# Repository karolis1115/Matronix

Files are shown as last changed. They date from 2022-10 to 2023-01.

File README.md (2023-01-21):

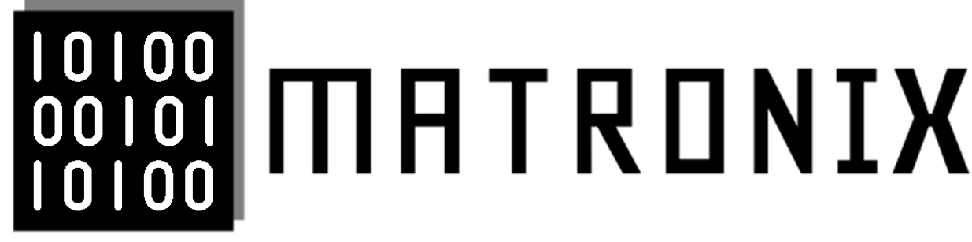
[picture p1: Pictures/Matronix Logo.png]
Matroniix

Saxion University of Applied Sciences Project Simulation & Integration 2022. 

# Team members
- Borna Modric 481209 481209@student.saxion.nl
- Joshua Phiri 511266 511266@student.saxion.nl
- Luuk Vulkers 523822 523822@student.saxion.nl
- Esther Ajumo 510127 510127@student.saxion.nl
- Karolis Juozapaitis 517546 517546@student.saxion.nl

# Goal
To make a modular, batery powered, wirelessly controlled RGB LED display board, while also designing a DC/DC converter based on given requirements.

# What is what
- CAD - CAD model designs for 3D printing
- PCB - Schematics, PCB, Gerber and other files
- Code - Place where all code is (test and main)
- Documents - Files such as Reports and project plans and so on
- Pictures - Project pictures and so on

# Libraries used
- LED Matrix Library + Recources https://github.com/hzeller/rpi-rgb-led-matrix
- ADS1x15 I2C ADC library https://learn.adafruit.com/adafruit-4-channel-adc-breakouts/python-circuitpython

# Sources
- https://www.raspberrypi.org/
- https://en.wikipedia.org/wiki/Raspberry_Pi
- https://github.com/hzeller/rpi-rgb-led-matrix

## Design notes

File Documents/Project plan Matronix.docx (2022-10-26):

# matronix Project plan

Project: MOdular led matrix scrolling display

Company: Matronix

Date:
Participants: | Project group LED matrix superstar McAwesomeville
| Borna Modric | 481209 | 481209@student.saxion.nl
| Joshua Phiri | 511266 | 511266@student.saxion.nl
| Luuk Vulkers | 523822 | 523822@student.saxion.nl
| Karolis Juozapaitis | 517546 | 517546@student.saxion.nl
| Esther Ajumo | 510127 | 510127@student.saxion.nl
Version | [1.1]
Clients | Saxion University of Applied Sciences
Tutor | Ali Yuksel

Table of Contents

# I. List of figures

# II. Abbreviations

DSP | Digital Signal Processing
FFT | Fast Fourier Transform
TL;DR | Too Long; Didn’t Read
LED | Light Emitting Diode

# introduction

## backround

Team Matronix is a company founded in 2022 as a part of a university project for the class Project Simulation & Realization. It consists of a group of five students from Saxion University of Applied Sciences majoring in Electrical Engineering.

This company has as a main goal to design a fully functional RGB LED sign and document every step of the development of the project.

The team is ready and confident to offer the best quality possible in their products and to comply to their clients’ demands.

## Description

Our team was tasked with creating a wireless programmable LED message sign board for users to display a message they wish. The team came up with a simple solution to the client’s needs, a sign with multiple modular displays that can be configured based on the user’s needs to create a better viewing experience for viewers.

## MoSCoW Method

One of the methods that will be used is The MoSCoW which operates by splitting the clients’ requirements into the most important ("Must"), all the way down to additions which would be nice to have, but are not necessary ("Could"), while also agreeing on things which are not feasible due to either timing issues or just not enough manpower ("Won’t have").

Must:

- Clearly visible from 10m
- Mobile
- Cordless
- Energy via battery
- Wireless data transmission
- Battery life for at least 1 hour
- Display must scroll the text.

Should:

- Battery life of 3 hours
- Wide enough for clear messages

Could:

- Display weather information when not used
- Speaker to read messages that are displayed
- Magnet connection
- Scalable and modular design
- Modular batteries
- Hot swappable batteries
- Display GIFs and videos
- Display images or videos
- Modules for additional features (temperature, humidity, and so on).

Won’t have:

- Infinitely scalable display
- Power form solar panels
- Replaceable LEDs (in case one breaks)
- Connect external Display (LCD, OLED, …) for extension
- Use device as monitor with display input (HDMI, VGA, Composite)

# Project Objectives

The project objectives include:

- The project is designed for maximum energy efficiency
- The text must be readable from a 10 meters distance.
- The text display should be multi color (RGB).
- The power supply via a battery.
- The communication to the system must be wireless
- The project group has regular updates with the client.

Aside from these strict requirements, we also implemented some secondary objectives we mean to implement in our project.

- The project will use multiple display modules side to side/stacked up.
- Make displays modular/work independently by disconnecting and reconnecting them
- Use high-current batteries to provide enough current
- Implement hot-swappable batteries
- 3D-printed and/or laser cut casing
- Use magnets and pogo-connectors to connect and disconnect the displays.
- If displays are disconnected, display different messages.

# Project activities

The project activities are divided into three stages

Preparatory stage:

- creation of a final concept
- Assigning organizational roles
- Making a project plan (also, in documentation)
- Cost estimation and budgeting
- Assigning deliverables

Design and implementation stage

- Making a functional and technical design (also, in documentation)
- Creating the product (hardware and software implementation)
- Testing the product
- Product assembly
- Progress report presentation (weekly)

Final stage

- Final Product delivery
- Documentation of the process in the form of a final report and presentation.

# Project boundaries (scope and pre-conditions)

The project has a duration of two quarters, which is about 4 months estimated. In terms of project width, there was no clear instruction on what is outside the scope of the project, only basic conditions. Based on the client’s requirements, the product should be mobile, cordless, powered by a battery, show a text in multicolor and readable from ten meters away. To make the project a success, those conditions must be fulfilled.

A budget of 75Euros has been given to acquire materials needed for this project, the final product is to be delivered by the sixth week of the second quarter

# Quality assurance

Matronix is committed to delivering a product of immense quality for our clients. Each employee has been involved in a prior project of some sort that requires them to apply their Electrical and Electronic skills and knowledge, in addition, the company has weekly meetings with the sponsor to ensure the product is developing in accordance with the requirements, moreover, the sponsor has access to various intermediate results (Project Plan, Functional Design, Technical Design & Final Report) and can, in turn, provide feedback when needed, thus validating the company’s claims of providing a high-end product at the end of this project.

Delivering a high-quality product crucial to a product's success. Therefore, the sponsor participates in the assessment of the project by testing the final product, they will thoroughly assess the product and decide whether it satisfies all the previously stated requirements or not

The sponsor will verify the following specifications to ensure that Matronix has in fact implemented these specifications in the product.

System specs

1. Designed for maximum energy efficiency ideally last for 30min on one charge

2. Text must be readable from a 10-meter distance and must be mobile

3. The text display should be multi-colour.

4. The power supply via a battery.

5. The communication to the system must be wirelessly.

Matronix will ensure this project is conducted with the utmost regard for the safety of each participant during the project, as well as creating a safe product for the client. There are no major safety threats involved with this project therefore, adhering to standard laboratory safety rules will be sufficient.

# Project organization

See Project Management from Roel Grit.

## Organisation

The Project organization is as follows:

- Joshua Electronics/Programming Group lead 511266@student.saxion.nl
- Karolis Electronics/Programming 517546@student.saxion.nl
- Borna Power delivery 481209@student.saxion.nl
- Esther Power delivery Minute taker 510127@student.saxion.nl
- Luuk Power/2D -3D modelling 523822@student.saxion.nl

## Information

Stakeholders

- The project group members
  - Borna Modric
  - Joshua Phiri
  - Luuk Vulkers
  - Karolis Juozapaitis
  - Esther Ajumo
- Tutor
  - Ali Yuksel
- The client
  - Saxion University of Applied Sciences

Communication

Within the project group we will weekly have two meetings. Aside from these, there is a Discord server for online communication and group calls. Minutes are updated weekly to check back on what has been happening, and it can be found on Blackboard.

Communication with the client will be had with regular client meetings. These will occur in the following weeks:

  - Week 1.3
    - Project Plan presentation
  - Week 1.6
    - Final Technical Design
  - Week 1.8
    - Midterm Presentation
  - Week 2.1
  - Week 2.4
  - Week 2.6
    - Demonstration final product

# Planning

- See GAANT Chart

# Costs and benefits

- As the project will be done using MOSCOW the final costs of the projects can only be predicted and are likely subject to change during the development process due to design changes and/or fixes. Simply speaking more features will likely include a higher cost. (Time and money)

Part & Link (Preliminary) | Quantity (Preliminary) | Price/pcs. (excl. VAT) (Preliminary)
64x32 RGB LED Matrix - 320x160mm (https://www.tinytronics.nl/shop/en/lighting/matrix/64x32-rgb-led-matrix-320x160-mm) | 2 Pcs. | € 21.07
1. ESP32-WROVER WiFi Module - PCB Antenna (https://www.tinytronics.nl/shop/en/communication-and-signals/wireless/wi-fi/modules/esp32-wrover-wifi-module-pcb-antenna-connector) | 1 pcs. | € 4.55
Battery
Misc.
DC/DC Converter
Logic Level Shifter

- While monetary costs are important to figure out if the project is in scope of the given budget. Time is a constraint that should also be taken into account. Even when everything is in order what could result in a failed project is incorrectly set deadlines for each part of the project. This should be taken into account in the GAANT chart.
- The end result will be a fully functional, battery powered and wirelessly controlled scrolling display board that would allow to quickly and easily communicate any important notices, information or updates without physically interacting with the device itself. Assuming enough time is present additional features will be added the features mentioned are included in the MOSCOW section
- As for the compensation of the team members. A sufficient grade is the bare minimum that Is agreed upon. Fulfilling all the stated requirements should result in a perfect grade.

# Bibliography

Grit, R. (2010). Project managment. Noordhoff Uitgevers.

# Appendix A Gantt chart

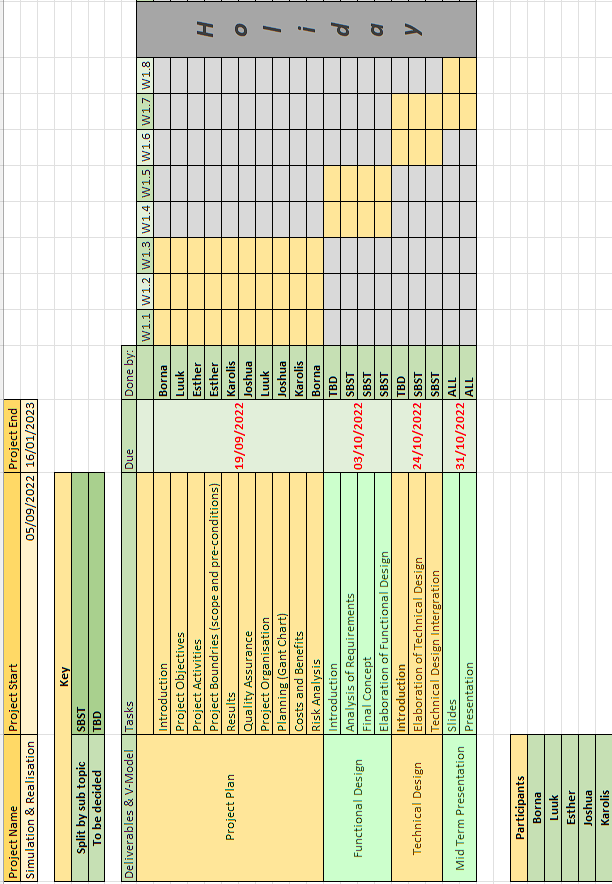
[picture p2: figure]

# Appendix B Risk analysis

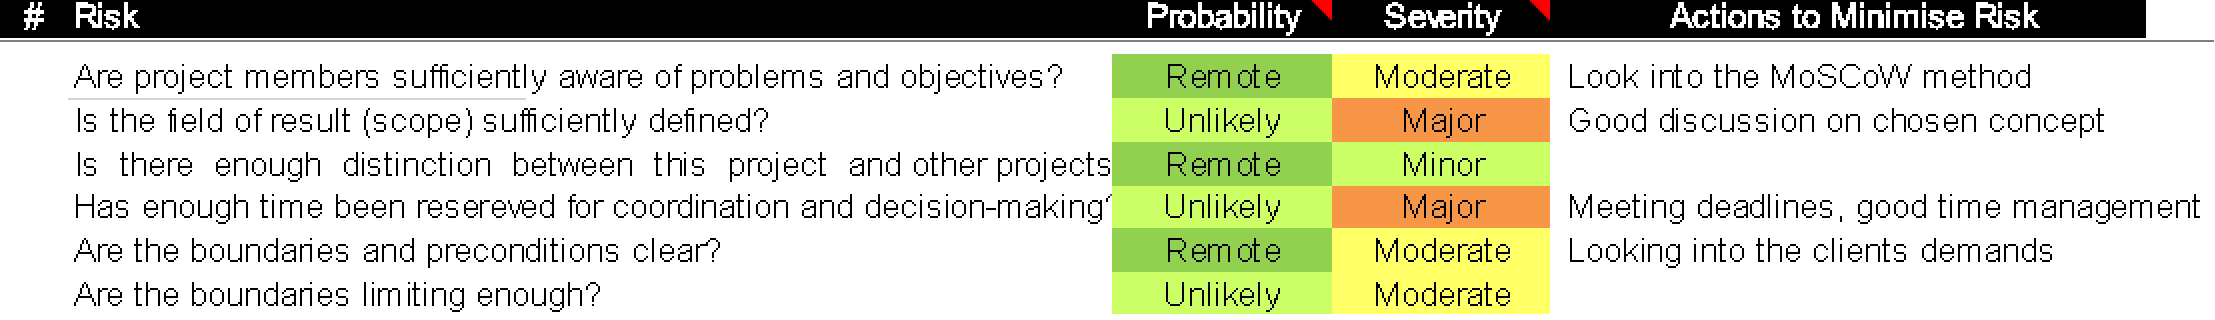
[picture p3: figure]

Project Plan version no: 2

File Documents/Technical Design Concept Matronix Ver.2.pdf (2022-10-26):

# 10/24/2022 Concept Technical

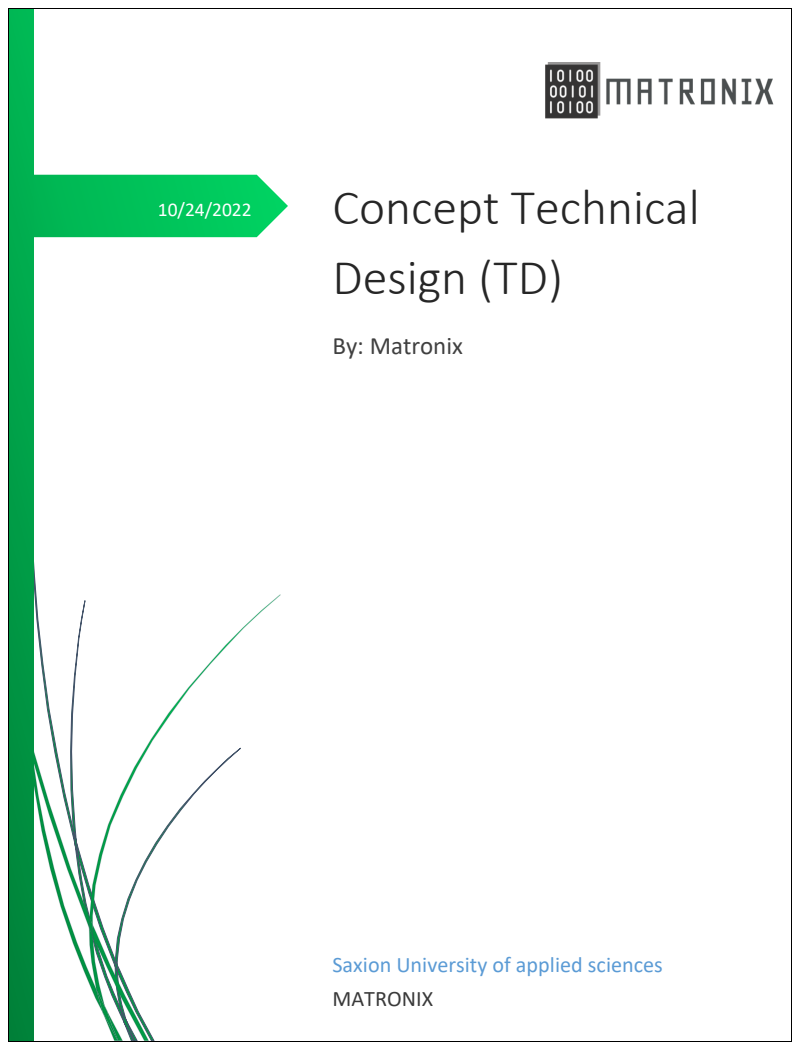
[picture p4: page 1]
Design (TD); By: Matronix

Saxion University of applied sciences
MATRONIX

Place, date: | Enschede, 13.10.2022.
Prepared by: | Team Matronix
| Luuk Vulkers | 523822 | 523822@student.saxion.nl
| Borna Modric | 481209 | 481209@student.saxion.nl
| Karolis Juozapaitis | 517546 | 517546@student.saxion.nl
| Esther Ajumo | 510127 | 510127@student.saxion.nl
| Joshua Phiri | 511266 | 511266@student.saxion.nl
Version number: | 1
Clients: | Ali Yuksel

iii

CONTENTS

iv

ABBREVIATIONS

- LED – Light Emitting Diode
- SDK – Source Development kit
- API – Application Programming Interface
- Li-Ion – Lithium Ion (Battery)
- BMS – Battery Management System

INTRODUCTION

Matronix’ technical design document is an overview of the technical details that will be considered during the implementation phase. These details include concept selection, component choice, and software and hardware flowcharts. This document will also help understand the main reasons for this project.

PROBLEM

The task provided to Team Matronix is to develop an RGB LED display sign for users to show their messages on it. The display must be readable from 10 meters, have at least 1 hour of battery life, the sign must be mobile and cordless.

`

ELABORATION OF CHOSEN PRINCIPLE TO TECHNICAL DESIGN

Matronix decided to go with a concept of detachable modular displays and hot swappable batteries The displayed text/graphics will adjust based on the number of displays connected, and brightness will be adjusted based on the amount of battery modules/pack connected.

OVERVIEW OF TECHNICAL DESIGN

In this concept, the LED displays will be detachable modules each with its own hot swappable battery. The display size can be increased or decreased by adding or removing LED Matrix modules and the batteries can be removed, replaced or charged without interrupting the operation of the display. This concept allows for the creation of a very efficient display having minimal power and size problems.

ELABORATION OF TECHNICAL DESIGN

ELECTRICAL & ELECTRONICS CIRCUITS

Show in Appendix A is a schematic of the PCB which will be physically attached to the main display, its purpose is to house the raspberry pi 4b Microcomputer as well as serve as a connection point for the other matrix panel modules to the Microcomputer.

Subcircuits of this schematic are panel detection circuits as well as battery pack detection circuitry.

The other schematics in Appendix A include the power delivery, charging and balancing circuitry.

SOFTWARE

- https://github.com/hzeller/rpi-rgb-led-matrix Library, Resources, Example code

- https://github.com/karolis1115/Matronix Project Repository (GitHub)

TECHNICAL DESIGN INTEGRATION

SAFETY

- Since the Li-Ion battery cells that are used to power the project are potentially dangerous and can lead to unforeseen consequences, care has been taken to implement multiple safety features:
- Over-charge protection
- Over-discharge protection
- Power delivery to the battery is controlled by a USB-C PD (Power delivery) integrated circuit
- Charging is controlled by a dedicated integrated circuit that charges and balances the 2 cells in series that will be used for the battery pack
- The Raspberry pi will have the capability to detect how many battery packs are connected to each display, if the amount of battery packs connected is less than the battery backs can handle the brightness will be dimmed to reduce power consumption and extend battery life. (Each pack can run 2 displays)

COSTS

Due to the sheer amount of engineering that goes into making a modular design of any product high costs are to be expected.

The main costs can be divided into these categories:

- Battery power and battery power management
- Charging
- Voltage conversion
- Battery cell protection (Undervoltage, Overcharging, Automatic sufficient charging supply assertion, …)
- Display and display management
- Display data level shifting
- Display detection using an ADC

- Display modularity integration

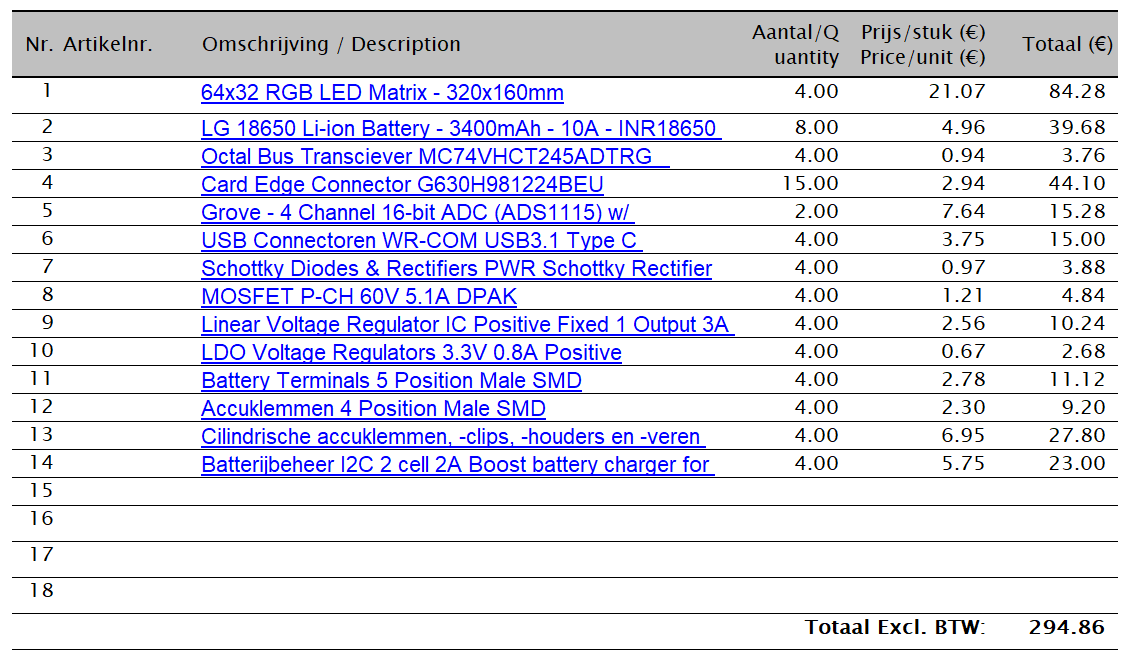
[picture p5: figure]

MAINTENANCE

A big part of the concept of this system is that the components are modular, this brings an advantage when a part becomes faulty or reaches its end of life it can be easily swapped out for a new one without soldering.

- The battery packs contain holders for the 18650 cells that will be used to power the device so it’s easy to repair the battery module itself.
- The raspberry pi, and display matrix modules will be connected to a PCB using headers so replacing either the Matrix panel or the raspberry pi itself should only require a screwdriver.

APPENDIX A: ELECTRICAL & ELECTRONIC

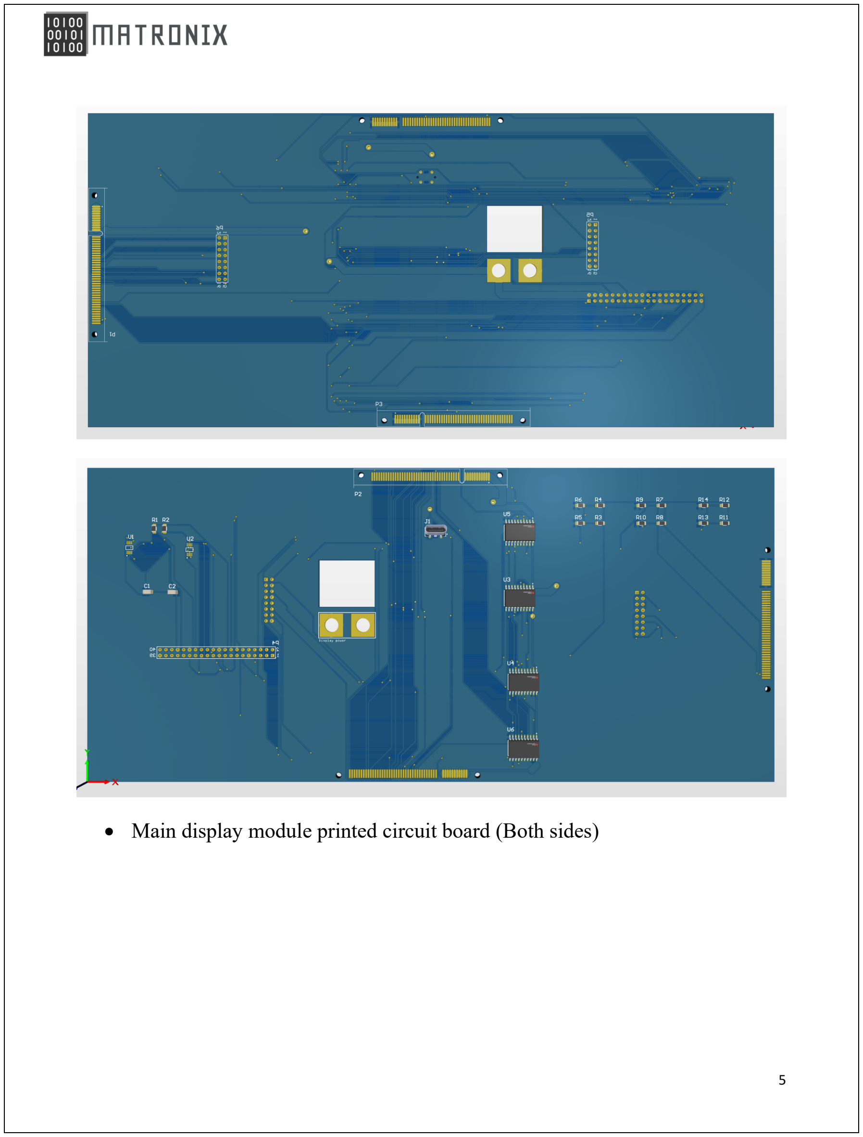
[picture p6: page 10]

- Main display module printed circuit board (Both sides)

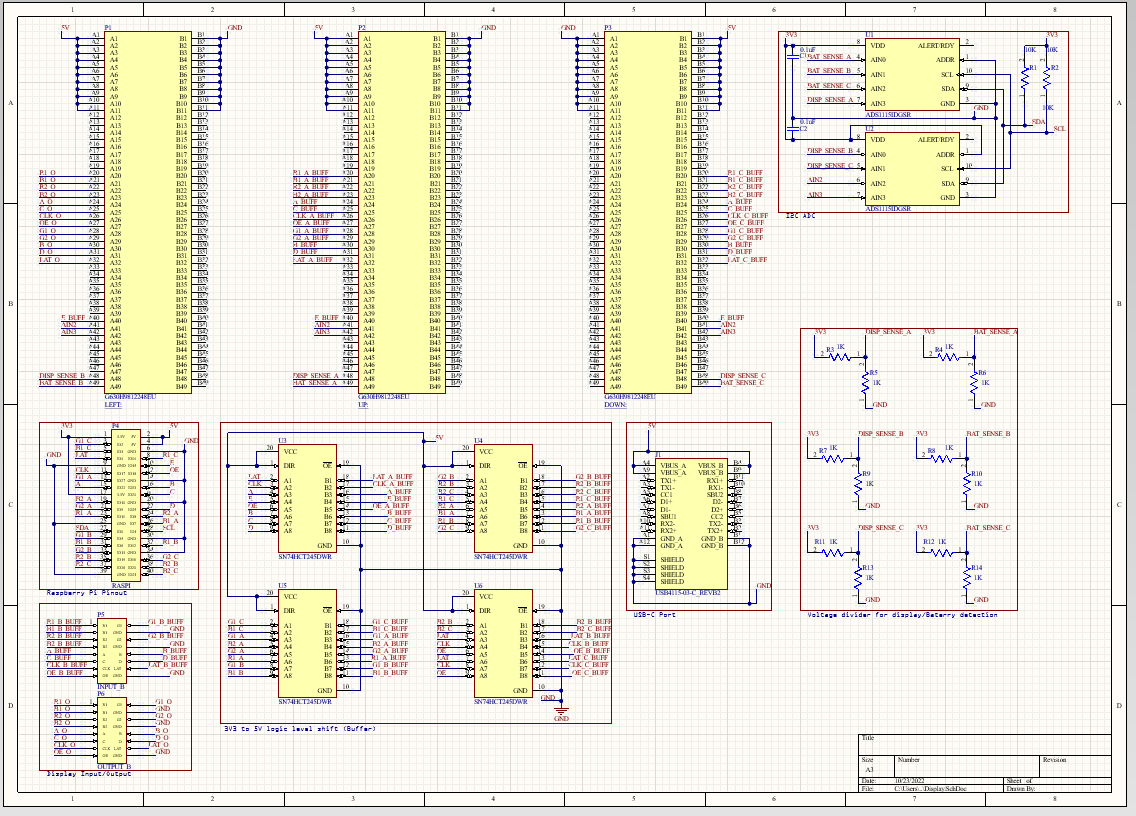
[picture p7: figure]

- Main display Circuit schematic (data output, Logic level conversion, baterry, display detection, ADC integration)

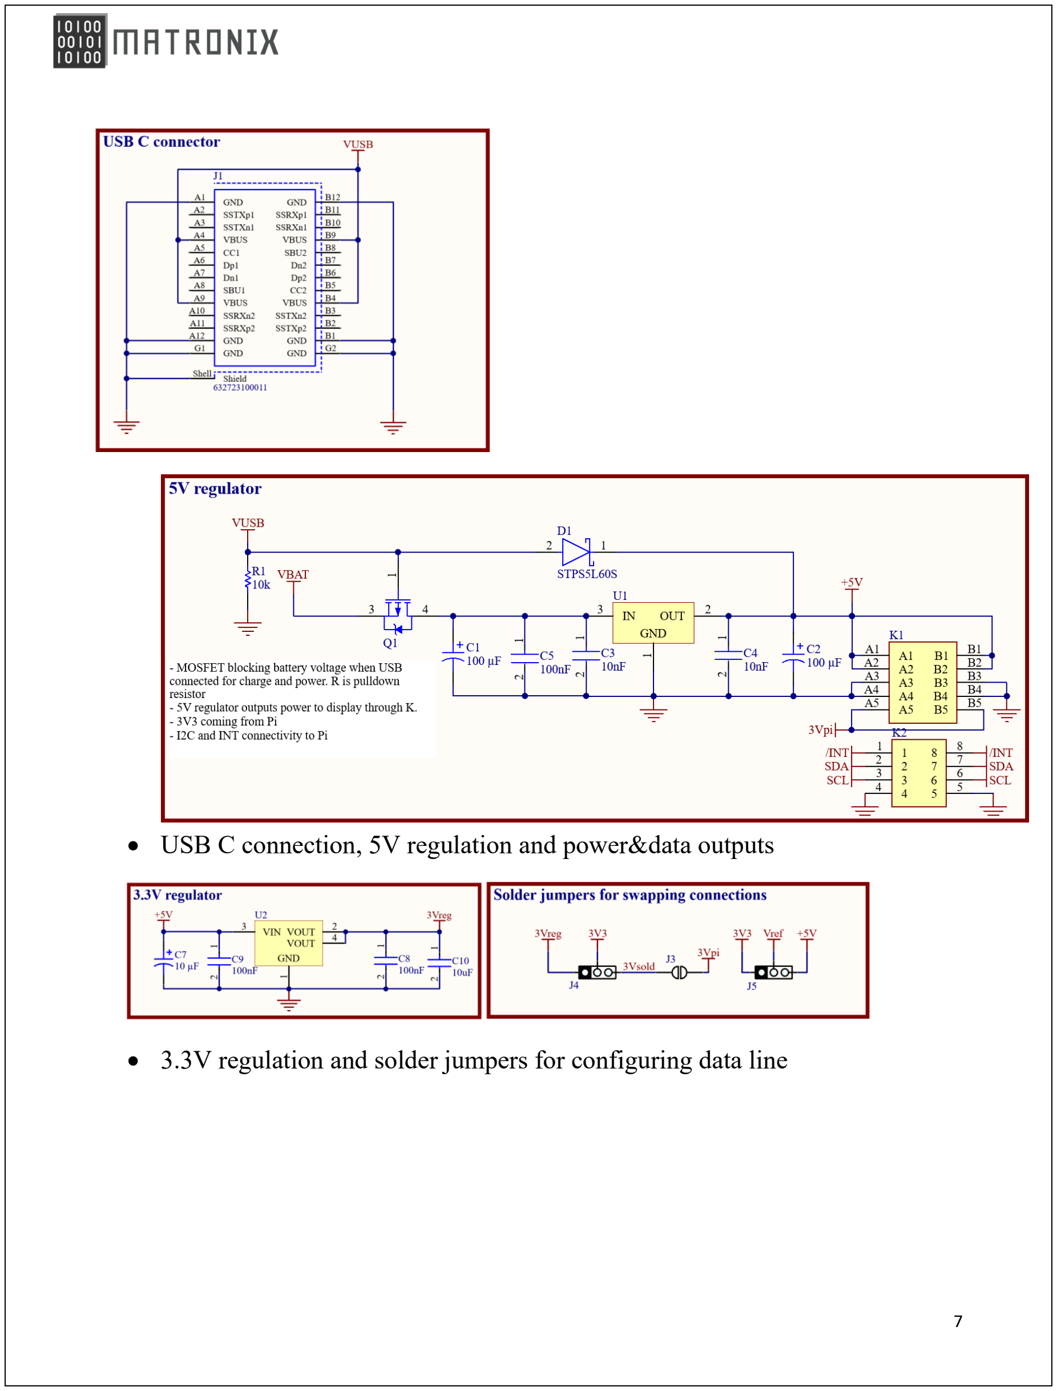
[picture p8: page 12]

- USB C connection, 5V regulation and power&data outputs
- 3.3V regulation and solder jumpers for configuring data line

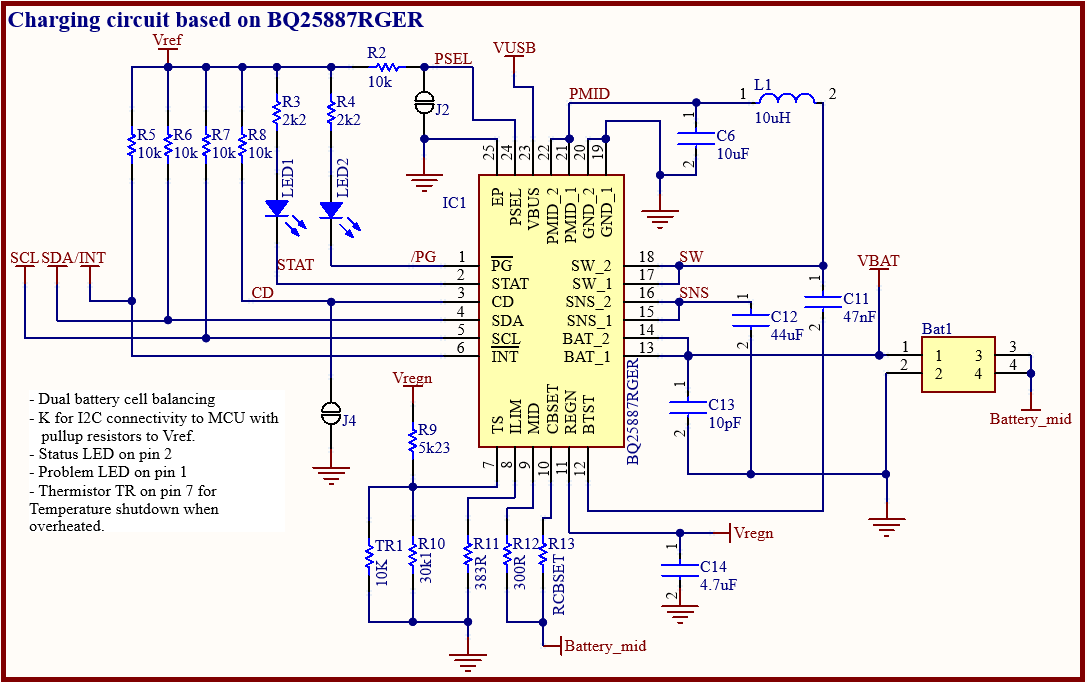
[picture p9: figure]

- Battery Charging/Protection

DISPLAY DEMONSTRATION

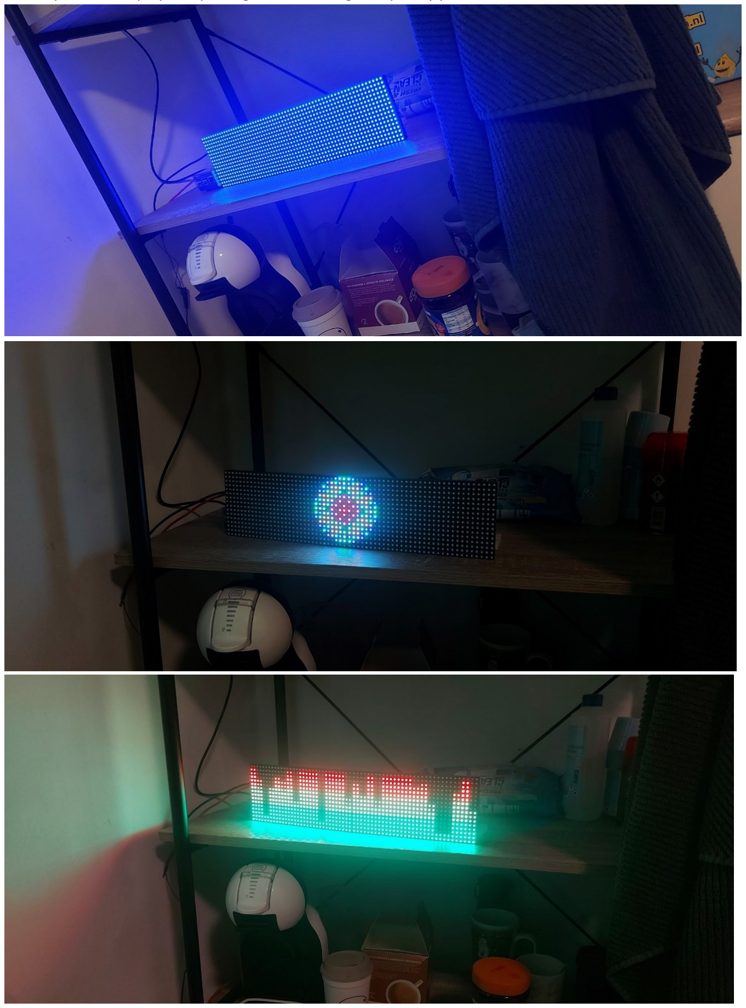
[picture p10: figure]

This depicts the displays outputting Patterns using a raspberry pi 4B

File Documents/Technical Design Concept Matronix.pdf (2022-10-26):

# 10/24/2022 Concept Technical

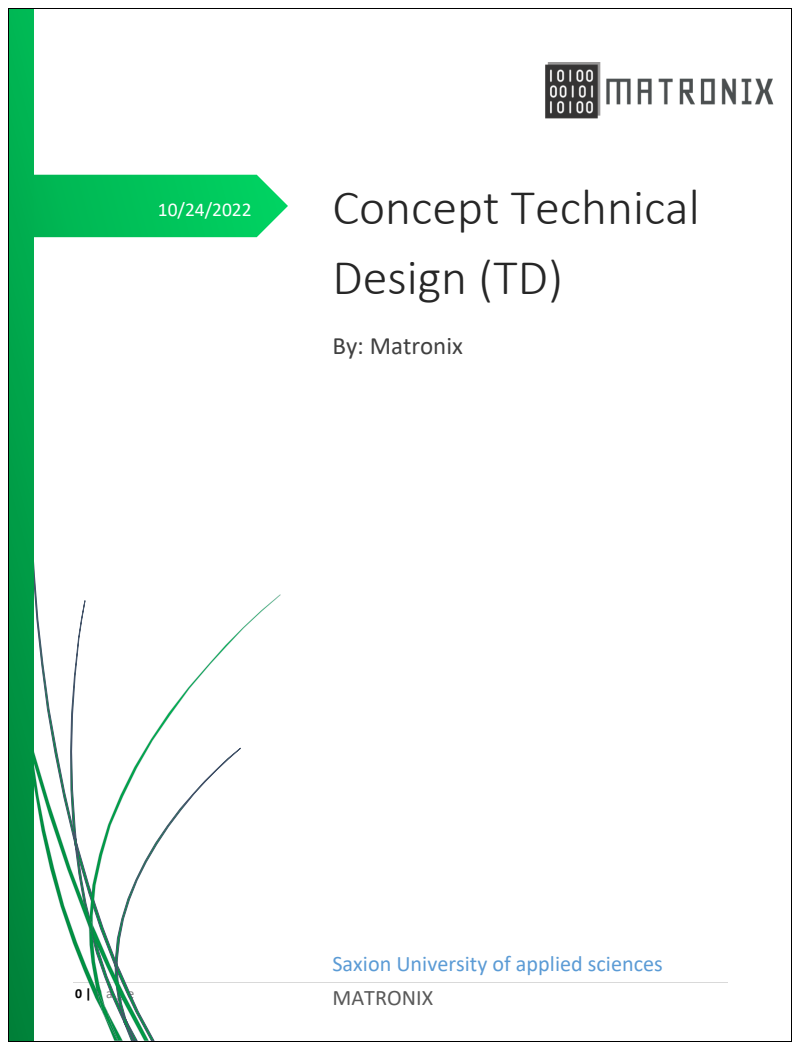
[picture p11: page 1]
Design (TD); By: Matronix

Saxion University of applied sciences
MATRONIX

Place, date: | Enschede, 13.10.2022.
Prepared by: | Team Matronix
| Luuk Vulkers | 523822 | 523822@student.saxion.nl
| Borna Modric | 481209 | 481209@student.saxion.nl
| Karolis Juozapaitis | 517546 | 517546@student.saxion.nl
| Esther Ajumo | 510127 | 510127@student.saxion.nl
| Joshua Phiri | 511266 | 511266@student.saxion.nl
Version number: | 1
Clients: | Ali Yuksel

iii

CONTENTS

iv

ABBREVIATIONS

- LED – Light Emitting Diode
- SDK – Source Development kit
- API – Application Programming Interface
- Li-Ion – Lithium Ion (Battery)
- BMS – Battery Management System

INTRODUCTION

Matronix’ technical design document is an overview of the technical details that will be considered during the implementation phase. These details include concept selection, component choice, and software and hardware flowcharts. This document will also help understand the main reasons for this project.

PROBLEM

The task provided to Team Matronix is to develop an RGB LED display sign for users to show their messages on it. The display must be readable from 10 meters, have at least 1 hour of battery life, the sign must be mobile and cordless.

`

ELABORATION OF CHOSEN PRINCIPLE TO TECHNICAL DESIGN

Matronix decided to go with a concept of detachable modular displays and hot swappable batteries The displayed text/graphics will adjust based on the number of displays connected, and brightness will be adjusted based on the amount of battery modules/pack connected.

OVERVIEW OF TECHNICAL DESIGN

In this concept, the LED displays will be detachable modules each with its own hot swappable battery. The display size can be increased or decreased by adding or removing LED Matrix modules and the batteries can be removed, replaced or charged without interrupting the operation of the display. This concept allows for the creation of a very efficient display having minimal power and size problems.

ELABORATION OF TECHNICAL DESIGN

ELECTRICAL & ELECTRONICS CIRCUITS

Show in Appendix A is a schematic of the PCB which will be physically attached to the main display, its purpose is to house the raspberry pi 4b Microcomputer as well as serve as a connection point for the other matrix panel modules to the Microcomputer.

Subcircuits of this schematic are panel detection circuits as well as battery pack detection circuitry.

The other schematics in Appendix A include the power delivery, charging and balancing circuitry.

SOFTWARE

- https://github.com/hzeller/rpi-rgb-led-matrix Library, Resources, Example code

- https://github.com/karolis1115/Matronix Project Repository (GitHub)

TECHNICAL DESIGN INTEGRATION

SAFETY

- Since the li-Ion battery cells that are used to power the project are potentially dangerous and can lead to unforeseen consequences, care has been taken to implement multiple safety features:
- Over-charge protection
- Over-discharge protection
- Power delivery to the battery is controlled by a USB-C PD (Power delivery) integrated circuit
- Charging is controlled by a dedicated integrated circuit that charges and balances the 2 cells in series that will be used for the battery pack
- The Raspberry pi will have the capability to detect how many battery packs are connected to each display, if the amount of battery packs connected is less than the battery backs can handle the brightness will be dimmed to reduce power consumption and extend battery life. (Each pack can run 2 displays)

COSTS

expensive

MAINTENANCE

A big part of the concept of this system is that the components are modular, this brings an advantage when a part becomes faulty or reaches it’s end of life it can be easily swapped out for a new one without soldering.

- The battery packs contain holders for the 18650 cells that will be used to power the device so it’s easy to repair the battery module itself.
- The raspberry pi, and display matrix modules will be connected to a PCB using headers so replacing either the Matrix panel or the raspberry pi itself should only require a screwdriver.

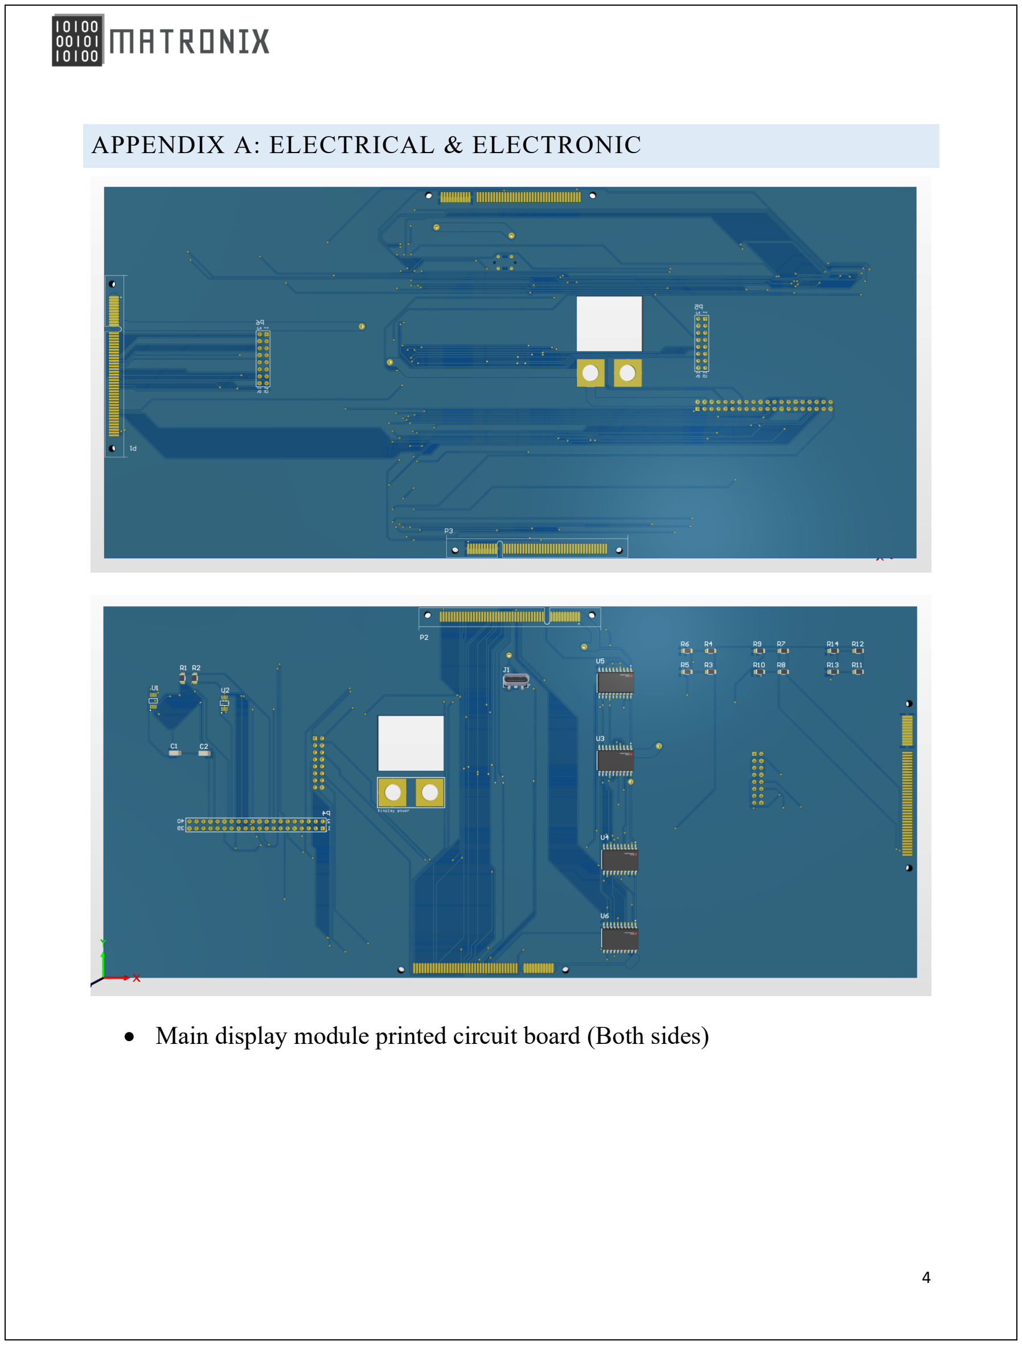
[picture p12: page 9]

APPENDIX A: ELECTRICAL & ELECTRONIC

- Main display module printed circuit board (Both sides)


- Main display Circuit schematic (data output, Logic level conversion, baterry, display detection, ADC integration)

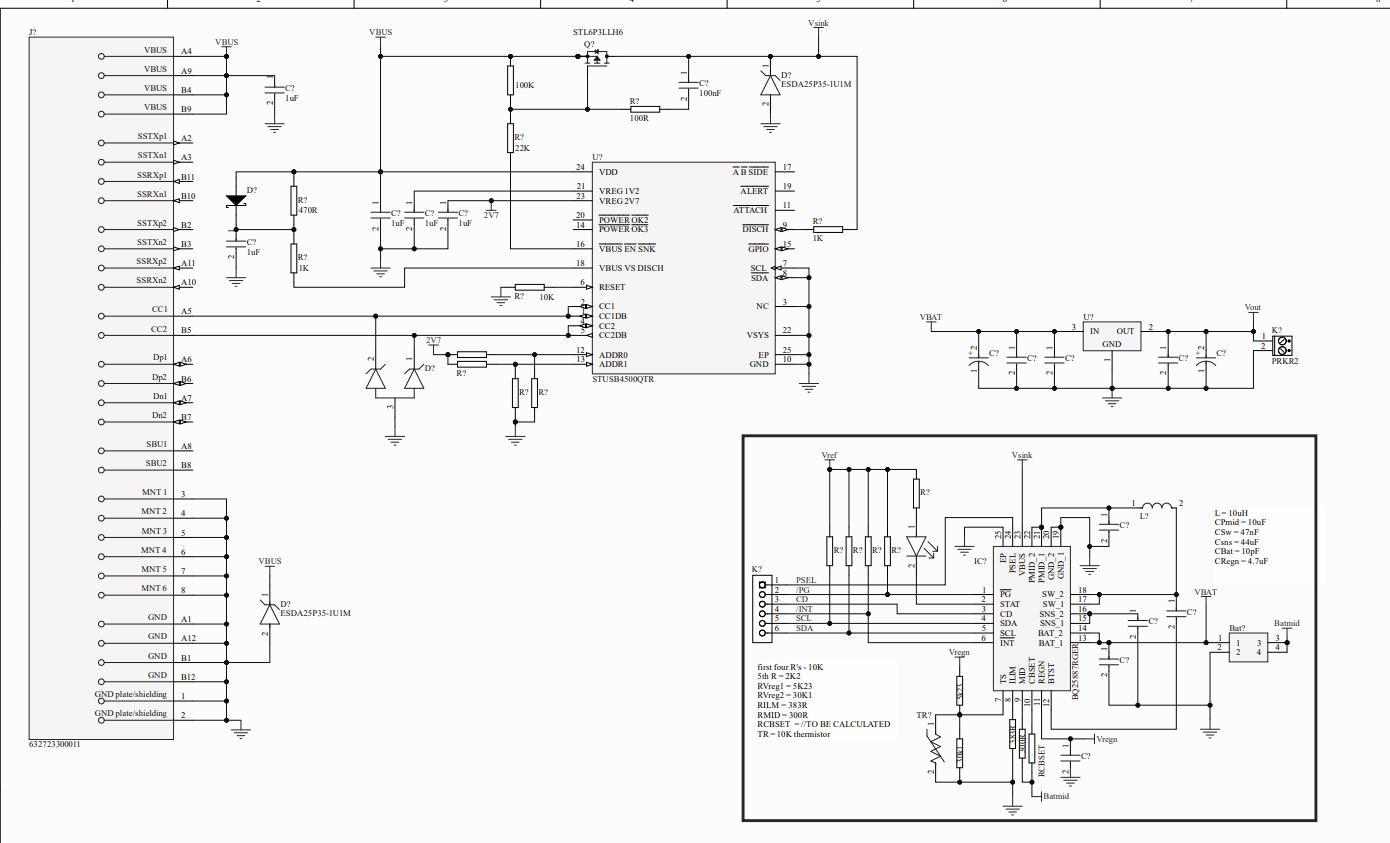
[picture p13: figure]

- Battery Charging/Protection and power output circuitry

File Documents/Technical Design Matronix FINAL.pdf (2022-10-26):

# 10/24/2022 Technical Design

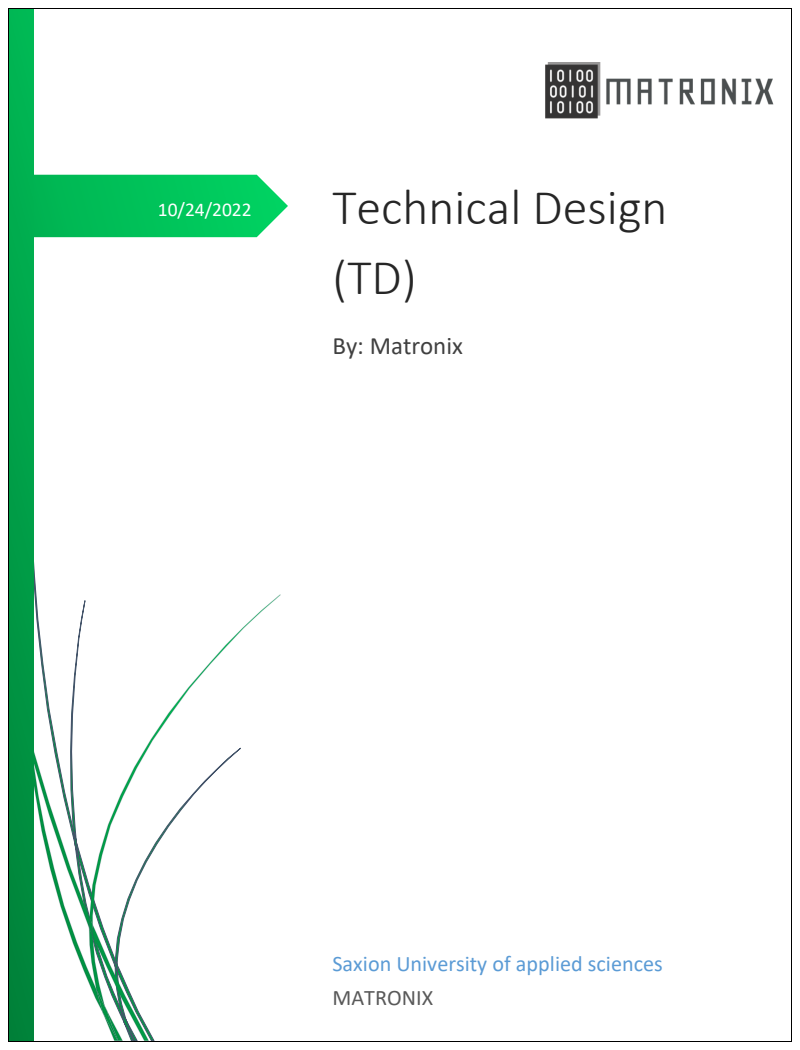
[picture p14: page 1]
By: Matronix

Saxion University of applied sciences
MATRONIX

Place, date: | Enschede, 13.10.2022.
Prepared by: | Team Matronix
| Luuk Vulkers | 523822 | 523822@student.saxion.nl
| Borna Modric | 481209 | 481209@student.saxion.nl
| Karolis Juozapaitis | 517546 | 517546@student.saxion.nl
| Esther Ajumo | 510127 | 510127@student.saxion.nl
| Joshua Phiri | 511266 | 511266@student.saxion.nl
Version number: | 1
Clients: | Ali Yuksel

iii

CONTENTS

iv

ABBREVIATIONS

- LED – Light Emitting Diode
- SDK – Source Development kit
- API – Application Programming Interface
- Li-Ion – Lithium Ion (Battery)
- BMS – Battery Management System

INTRODUCTION

Matronix’ technical design document is an overview of the technical details that will be considered during the implementation phase. These details include concept selection, component choice, and software and hardware flowcharts. This document will also help understand the main reasons for this project.

PROBLEM

The task provided to Team Matronix is to develop an RGB LED display sign for users to show their messages on it. The display must be readable from ten meters, have at least 1 hour of battery life, the sign must be mobile and cordless.

`

ELABORATION OF CHOSEN PRINCIPLE TO TECHNICAL DESIGN

The concept chosen by Matronix abides to all the requirements requested by the stakeholders:

- Wireless data transmission – Using Raspberry pi’s Wi-Fi and SSH or Webserver.
- Clearly readable from ten meters far – The chosen display size provides adequate clarity and readability. In case the desired distance is largely more than ten meters additional modules can be easily attached.
- The display will run for at least an hour as power will be provided by battery modules consisting of two rechargeable 18650 Li-Ion battery cells connected in series with charging, power regulation and safety features. One battery module will be chosen per display to achieve maximum performance and battery life.

The summary or additional features that this product will have are as follow:

- Detachable modular displays
- Hot swappable batteries – Display operation will not be interrupted if at least one battery module is connected
- Automatic Displayed text/graphics Size adjustment based on the amount of displays connected
- Automatic brightness adjustment based on the amount of battery modules connected
- Mounting the displays back-to back will allow displaying the same information from the front and back for people to see from both sides of the display.
- The ports that connect the display modules will also allow for additional modules or sensors to be connected by the I2C BUS and 2 ADC inputs, to add to that any unused IO that would normally be used for additional display modules can be used for additional peripherals instead.

OVERVIEW OF TECHNICAL DESIGN

In this concept, the LED displays will be detachable modules each with its own hot swappable battery. The display size can be increased or decreased by adding or removing LED Matrix modules and the batteries can be removed, replaced, or charged without interrupting the operation of the display. This concept allows for the creation of a very efficient display having minimal power and size problems.

ELABORATION OF TECHNICAL DESIGN

ELECTRICAL & ELECTRONICS CIRCUITS

Show in Appendix A is a schematic of the PCB which will be physically attached to the main display, its purpose is to house the raspberry pi 4b Microcomputer as well as serve as a connection point for the other matrix panel modules to the Microcomputer.

Subcircuits of this schematic are panel detection circuits as well as battery pack detection circuitry.

The other schematics in Appendix A include the power delivery, charging and balancing circuitry.

SOFTWARE

- https://github.com/hzeller/rpi-rgb-led-matrix Library, Resources, Example code
- https://github.com/karolis1115/Matronix Project Repository (GitHub)

TECHNICAL DESIGN INTEGRATION

SAFETY

- Since the Li-Ion battery cells that are used to power the project are potentially dangerous and can lead to unforeseen consequences, care has been taken to implement multiple safety features:
- Over-charge protection

- Over-discharge protection
- Power delivery to the battery is controlled by a USB-C PD (Power delivery) integrated circuit
- Charging is controlled by a dedicated integrated circuit that charges and balances the two cells in series that will be used for the battery pack
- The Raspberry pi will have the capability to detect how many battery packs are connected to each display, if the amount of battery packs connected is less than the battery backs can handle the brightness will be dimmed to reduce power consumption and extend battery life. (Each pack can run two displays)

COSTS

Due to the sheer amount of engineering that goes into making a modular design of any product excessive costs are to be expected.

The main costs can be divided into these categories:

- Battery power and battery power management
- Battery cell costs
- Charging
- Voltage conversion
- Battery cell protection (Undervoltage, Overcharging, Automatic sufficient charging supply assertion, …)
- Display and display management
- Display module costs
- Display data voltage level shifting
- Display detection using an ADC
- Display modularity integration

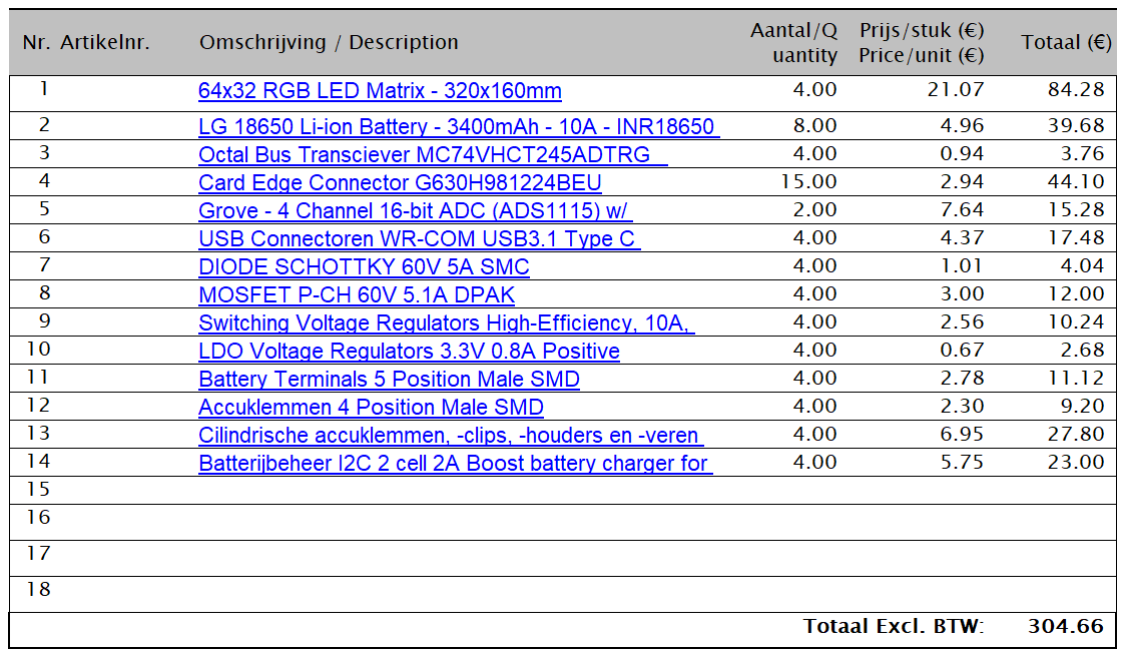
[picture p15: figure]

MAINTENANCE

A big part of the concept of this system is that the components are modular, this brings an advantage when a part becomes faulty or reaches its end of life it can be easily swapped out for a new one without soldering.

- The battery packs contain holders for the 18650 cells that will be used to power the device, so it is easy to repair the battery module itself.
- The raspberry pi, and display matrix modules will be connected to a PCB using headers so replacing either the Matrix panel or the raspberry pi itself should only require a screwdriver.

APPENDIX A: ELECTRICAL & ELECTRONIC

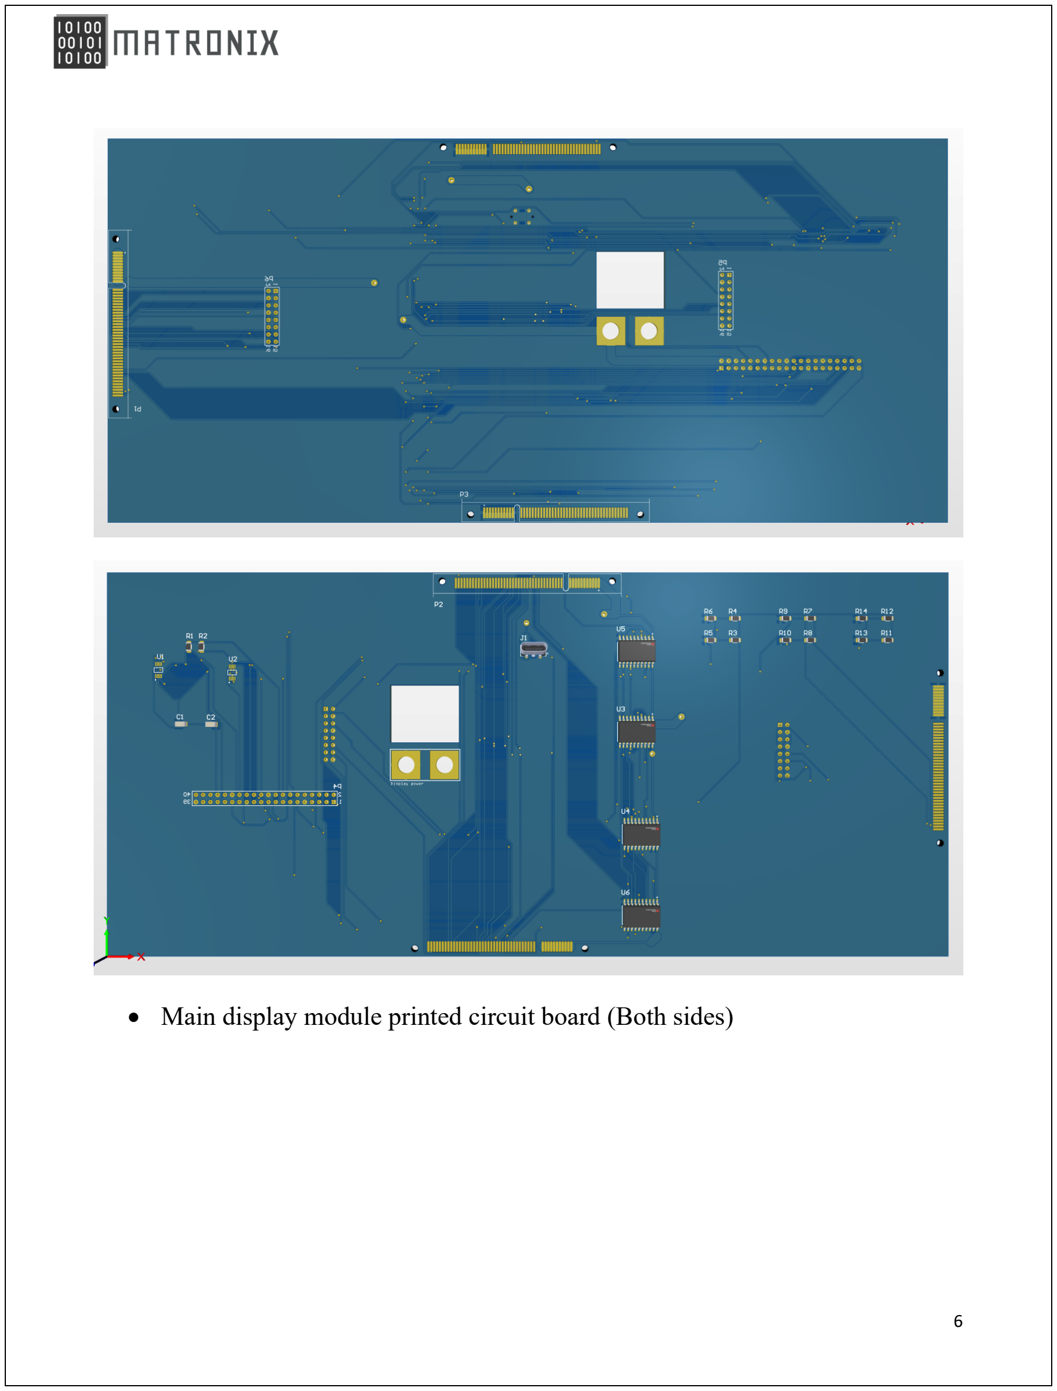
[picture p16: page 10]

- Main display module printed circuit board (Both sides)


- Main display Circuit schematic (data output, Logic level conversion, battery, display detection, ADC integration)

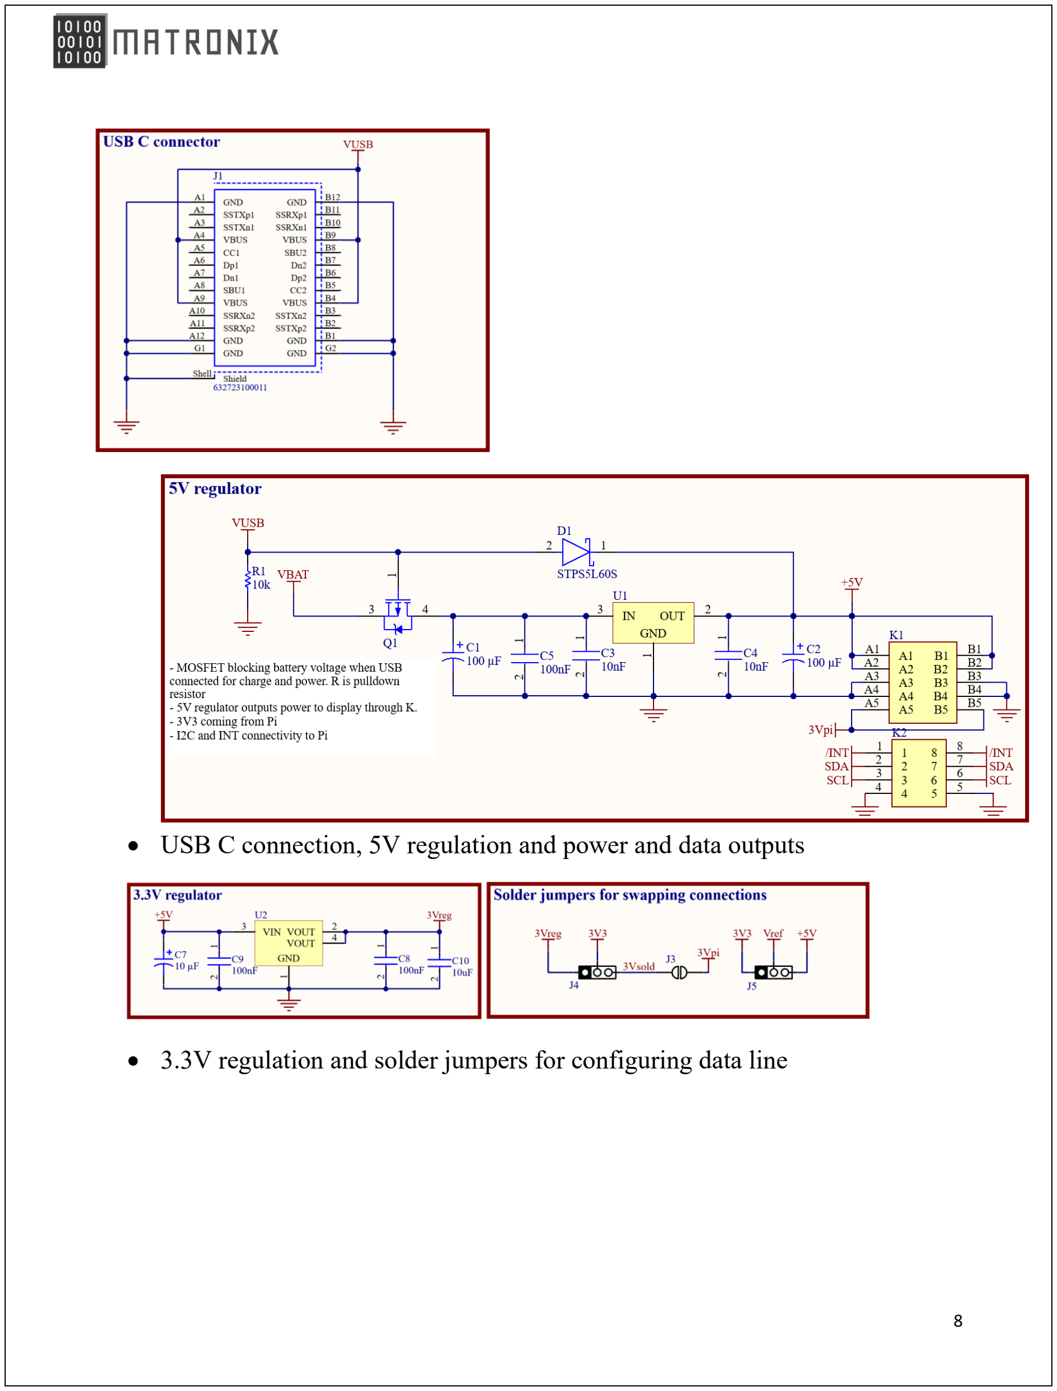
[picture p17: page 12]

- USB C connection, 5V regulation and power and data outputs
- 3.3V regulation and solder jumpers for configuring data line


- Battery Charging/Protection

DISPLAY DEMONSTRATION
This depicts the displays outputting Patterns using a raspberry pi 4B

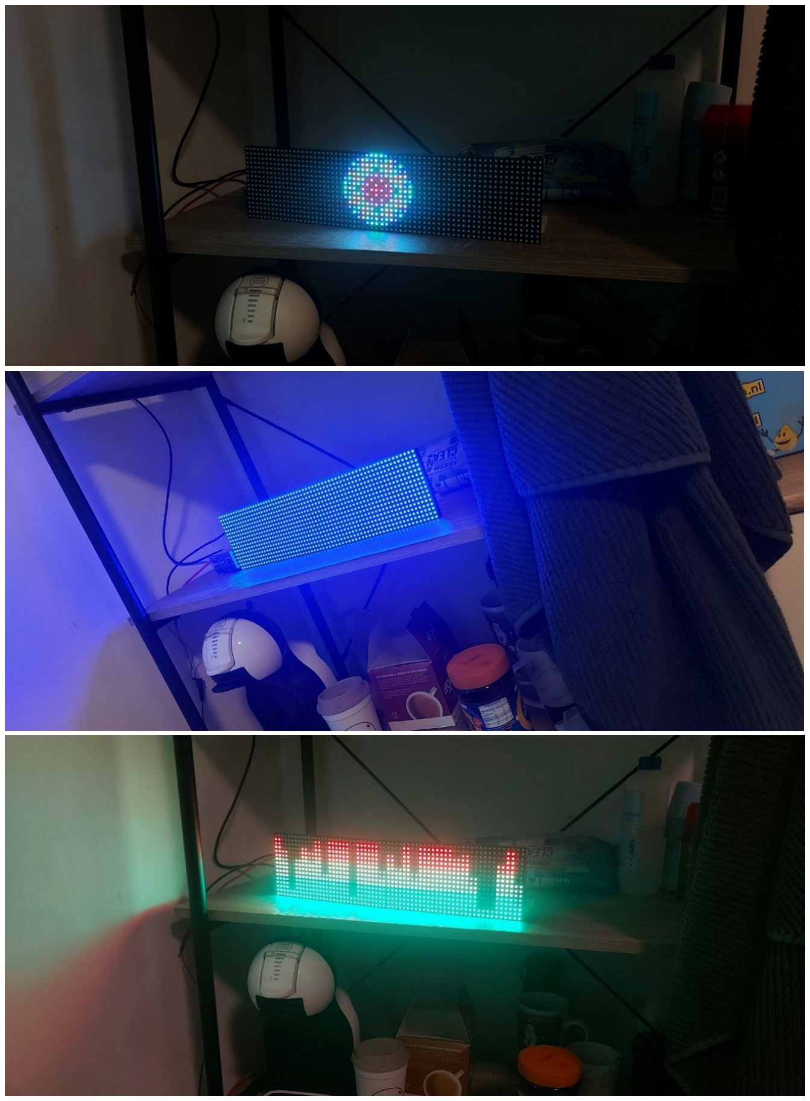
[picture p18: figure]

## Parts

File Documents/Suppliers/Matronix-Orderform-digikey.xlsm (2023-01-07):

Bestelweb
Bestelformulier voor LED / LED Orderform
Dit formulier kan worden gebruikt voor het aanvragen (per mail) voor het plaatsen van een order in Bestelweb.
Alle opdrachten voor levering van goederen en diensten die resulteren in een factuur aan SAXION dienen in Bestelweb te worden geregistreerd. This orderform is used for requesting goods via mail.
Aanvraag
Naam/Name: |  | Matronix
Datum/Date: |  | 2022-12-03
Budgethouder: |  | Ali Yuksel
Kostenplaats: |  | 1150375
Kostensoort: |  | Parts Digikey
Prijzen zijn exclusieve BTW / Prizes are excl. VAT
Leverancier/ Vendor: |  | Saxion
Artikelen/Articles/diensten/Services:
Nr. | Artikelnr. | Omschrijving / Description | Aantal/Quantity | Prijs/stuk (€) Price/unit (€) | Totaal (€)
1 |  | Octal Bus Transciever MC74VHCT245ADTRG (https://www.digikey.nl/en/products/detail/onsemi/MC74VHCT245ADTRG/1481109) | 4.00 | 0.94 | 3.76
2 |  | Card Edge Connector G630H9812248EU (https://www.digikey.nl/en/products/detail/amphenol-cs-fci/G630H9812248EU/5423806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) | 15.00 | 2.86 | 42.90
3 |  | ESQ-108-12-T-S Stackable headers (https://www.digikey.nl/en/products/detail/samtec-inc/ESQ-108-12-T-S/6692048) | 1.86 | 16.00 | 29.76
4 |  | AOD482 N-channel Mosfet (https://www.digikey.com/en/products/detail/alpha-omega-semiconductor-inc/AOD482/2353942) | 1.00 | 1.09 | 1.09
5 |  | B82559B0303A016 30uH inductor (https://www.digikey.nl/en/products/detail/epcos-tdk-electronics/B82559B0303A016/13165574) | 1.00 | 5.72 | 5.72
6 |  | FDB035N10A N-Channel Mosfet (https://www.digikey.nl/nl/products/result?s=N4IgTCBcDaILYEMAeBWALATgAwDcDGAjFsViALoC%2BQA) | 1.00 | 7.34 | 7.34
7 |  | STD17NF03LT4 N-Channel Mosfet (https://www.digikey.com/en/products/detail/stmicroelectronics/STD17NF03LT4/654484)
8
9
10
11
12
13
14
15
 |  |  |  | Totaal Excl. BTW: | 90.57

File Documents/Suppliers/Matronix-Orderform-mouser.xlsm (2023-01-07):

Bestelweb
Bestelformulier voor LED / LED Orderform
Dit formulier kan worden gebruikt voor het aanvragen (per mail) voor het plaatsen van een order in Bestelweb.
Alle opdrachten voor levering van goederen en diensten die resulteren in een factuur aan SAXION dienen in Bestelweb te worden geregistreerd. This orderform is used for requesting goods via mail.
Aanvraag
Naam/Name: |  | Matronix
Datum/Date: |  | 2022-12-11
Budgethouder: |  | Ali Yuksel
Kostenplaats: |  | 1150375
Kostensoort: |  | Parts Mouser
Prijzen zijn exclusieve BTW / Prizes are excl. VAT
Leverancier/ Vendor: |  | Saxion
Artikelen/Articles/diensten/Services:
Nr. | Artikelnr. | Omschrijving / Description | Aantal/Quantity | Prijs/stuk (€) Price/unit (€) | Totaal (€)
1 |  | Cilindrische accuklemmen, -clips, -houders en -veren SMT Polarized Holder Dual 18650 Batterie (https://nl.mouser.com/ProductDetail/Keystone-Electronics/1048P?qs=9%252Bwcgl%2FJqd1h8Vx3IFpTxA%3D%3D) | 4.00 | 6.95 | 27.80
2 |  | Batterijbeheer I2C 2 cell 2A Boost battery charger for USB input and integrated cell balancing 24-VQFN -40 to 85 (https://nl.mouser.com/ProductDetail/Texas-Instruments/BQ25887RGER?qs=T3oQrply3y%252BX5K0CWEHEpA%3D%3D) | 4.00 | 5.75 | 23.00
3 |  | MP8771GQ-P Buck Converted IC (https://nl.mouser.com/ProductDetail/Monolithic-Power-Systems-MPS/MP8771GQ-P?qs=F5EMLAvA7IAqXJOcxw0ugg%3D%3D) | 4.00 | 3.05 | 12.20
4 |  | USB Connectors WR-COM USB3.1 Type C SuperSpeed+ Rcpt (https://nl.mouser.com/ProductDetail/Wurth-Elektronik/632723100011?qs=NK6InXoXhq4o62C9ULXLjQ%3D%3D) | 5.00 | 4.37 | 21.85
5 |  | 15A TRENCH SCHOTTKY BARRIER RECTIFIER (https://nl.mouser.com/ProductDetail/Diodes-Incorporated/SDT15H100P5-7?qs=W0yvOO0ixfH5hR%252B8TQOTJw%3D%3D) | 9.00 | 0.87 | 7.83
6 |  | TE Connectivity 1747785-1 Male Battery connector (https://nl.mouser.com/ProductDetail/TE-Connectivity/1747785-1?qs=wds1f20rnm3JQGfMkfdK9A%3D%3D) | 4.00 | 3.50 | 14.00
7 |  | 1747786-1 Baterry connector Female (https://nl.mouser.com/ProductDetail/TE-Connectivity/1747786-1?qs=wds1f20rnm0qz67bnaJ%252Bjw%3D%3D) | 4.00 | 2.91 | 11.64
8 |  | Power Inductors - SMD WE-HCI 1.2uH 12A (https://nl.mouser.com/ProductDetail/Wurth-Elektronik/744323120?qs=VxkwJfKV0FTKuaHdv4meEw%3D%3D) | 4.00 | 4.12 | 16.48
9 |  | Power Inductors - SMD 10uH (https://nl.mouser.com/ProductDetail/Bourns/SRP5030T-100M?qs=Zq5ylnUbLm5GUjmD8oSVdQ%3D%3D) | 4.00 | 1.41 | 5.64
10 |  | MOSFET P-Ch -30V (https://nl.mouser.com/ProductDetail/Toshiba/TPC8125LQS?qs=QrGA9tEX17PL4hDY9VQr6A%3D%3D) | 4.00 | 0.77 | 3.08
11 |  | Bipolar Transistors (https://nl.mouser.com/ProductDetail/Nexperia/BC817K-25HVL?qs=vLWxofP3U2wvMmuwDEtSXA%3D%3D) | 8.00 | 0.29 | 2.32
12 |  | NTC (Negative Temperature Coefficient) Thermistors 10kohm 1% (https://nl.mouser.com/ProductDetail/Semitec/103AT-2?qs=wgO0AD0o1vvcDzsKguD%252Bew%3D%3D) | 4.00 | 0.96 | 3.84
13 |  | Op-amp (https://nl.mouser.com/ProductDetail/Microchip-Technology-Atmel/MCP602T-I-SN?qs=TQnwojwsYvjO8LpVbD0MHw%3D%3D) | 1.00 | 0.75 | 0.75
14
15 |  | Current Sense Resistor 10mOhms (https://nl.mouser.com/ProductDetail/YAGEO/PA1206FRE470R01Z?qs=eP2BKZSCXI4yn1fb7Ph6Dg%3D%3D) | 2.00 | 0.58 | 1.16
16 |  | Current sense IC (https://nl.mouser.com/ProductDetail/Texas-Instruments/INA219AIDR?qs=XGzIaZb%2FFYIE5YcOHTnKDA%3D%3D) | 2.00 | 2.62 | 5.24
17 |  | USB-C trigger module (https://nl.mouser.com/ProductDetail/onsemi-Fairchild/FUSB302B11MPX?qs=jFK2DQXLaBwFFZq6iARIyw%3D%3D) | 1.00 | 1.75 | 1.75
18 |  | Resistor Networks & Arrays 100kOHM Precision-Matched Resistor-Divider in SOT23 (https://nl.mouser.com/ProductDetail/Maxim-Integrated/MAX5490VC10000+T?qs=nuXzIS8loXEuiMCu1GlPFw%3D%3D) | 1.00 | 4.78 | 4.78
19
20
21
 |  |  |  | Totaal Excl. BTW: | 163.36

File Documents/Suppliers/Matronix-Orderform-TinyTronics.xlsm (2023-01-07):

Bestelweb
Bestelformulier voor LED / LED Orderform
Dit formulier kan worden gebruikt voor het aanvragen (per mail) voor het plaatsen van een order in Bestelweb.
Alle opdrachten voor levering van goederen en diensten die resulteren in een factuur aan SAXION dienen in Bestelweb te worden geregistreerd. This orderform is used for requesting goods via mail.
Aanvraag
Naam/Name: |  | Matronix
Datum/Date: |  | 2022-12-03
Budgethouder: |  | Ali Yuksel
Kostenplaats: |  | 1150375
Kostensoort: |  | Parts TinyTronics
Prijzen zijn exclusieve BTW / Prizes are excl. VAT
Leverancier/ Vendor: |  | Saxion
Artikelen/Articles/diensten/Services:
Nr. | Artikelnr. | Omschrijving / Description | Aantal/Quantity | Prijs/stuk (€) Price/unit (€) | Totaal (€)
1 | Tinytronics | 64x32 RGB LED Matrix - 320x160mm (https://www.tinytronics.nl/shop/en/lighting/matrix/64x32-rgb-led-matrix-320x160-mm) | 2.00 | 21.07 | 42.14
2 | Tinytronics | LG 18650 Li-ion Battery - 3400mAh - 10A - INR18650 MJ1 (https://www.tinytronics.nl/shop/en/power/batteries/18650/lg-18650-li-ion-battery-3400mah-10a-inr18650-mj1) | 8.00 | 4.96 | 39.68
3 |  | NE555 8-pins DIP 555 Timer (https://www.tinytronics.nl/shop/en/components/ics-and-microcontroller-chips/ics/ne555p) | 1.00 | 0.50 | 0.50
4
5
6
7
8
9
10
11
12
13
14
15
16
 |  |  |  | Totaal Excl. BTW: | 82.32

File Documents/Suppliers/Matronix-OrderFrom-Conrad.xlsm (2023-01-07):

Bestelweb
Bestelformulier voor LED / LED Orderform
Dit formulier kan worden gebruikt voor het aanvragen (per mail) voor het plaatsen van een order in Bestelweb.
Alle opdrachten voor levering van goederen en diensten die resulteren in een factuur aan SAXION dienen in Bestelweb te worden geregistreerd. This orderform is used for requesting goods via mail.
Aanvraag
Naam/Name: |  | Matronix
Datum/Date: |  | 2022-12-03
Budgethouder: |  | Ali Yuksel
Kostenplaats: |  | 1150375
Kostensoort: |  | Parts Conrad
Prijzen zijn exclusieve BTW / Prizes are excl. VAT
Leverancier/ Vendor: |  | Saxion
Artikelen/Articles/diensten/Services:
Nr. | Artikelnr. | Omschrijving / Description | Aantal/Quantity | Prijs/stuk (€) Price/unit (€) | Totaal (€)
1 |  | TRU COMPONENTS Si rectifier diode TC-1N4007 DO-204AL 1000 V 1 A (https://www.conrad.nl/nl/p/tru-components-si-gelijkrichter-diode-tc-1n4007-do-204al-1000-v-1-a-1581845.html) | 3.00 | 0.07 | 0.21
2
3
4
5
6
7
8
9
10
11
12
13
14
15
16
17
18
19
20
21
22
23
24
25
26
 |  |  |  | Totaal Excl. BTW: | 0.21

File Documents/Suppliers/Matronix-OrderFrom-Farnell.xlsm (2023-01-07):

Bestelweb
Bestelformulier voor LED / LED Orderform
Dit formulier kan worden gebruikt voor het aanvragen (per mail) voor het plaatsen van een order in Bestelweb.
Alle opdrachten voor levering van goederen en diensten die resulteren in een factuur aan SAXION dienen in Bestelweb te worden geregistreerd. This orderform is used for requesting goods via mail.
Aanvraag
Naam/Name: |  | Matronix
Datum/Date: |  | 2022-12-03
Budgethouder: |  | Ali Yuksel
Kostenplaats: |  | 1150375
Kostensoort: |  | Parts Farnell
Prijzen zijn exclusieve BTW / Prizes are excl. VAT
Leverancier/ Vendor: |  | Saxion
Artikelen/Articles/diensten/Services:
Nr. | Artikelnr. | Omschrijving / Description | Aantal/Quantity | Prijs/stuk (€) Price/unit (€) | Totaal (€)
1 |  | Inductor (SMD) 20 µH (https://nl.farnell.com/epcos/b82559a0203a016/inductor-20uh-semishielded-7-7a/dp/3212645?st=20uh) | 1.00 | 5.13 | 5.13
2 |  | LM555CN/NOPB - 555 Timer (https://nl.farnell.com/texas-instruments/lm555cn-nopb/ic-timer-programmable-15ma-8dip/dp/3121177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) | 1.00 | 1.82 | 1.82
3 |  | 25V zener diode (https://nl.farnell.com/on-semiconductor/mmsz4710t1g/zener-diode-aec-q101-25v-0-5w/dp/2727985?st=25v%20diode) | 1.00 | 0.25 | 0.25
4
5
6
7
8
9
10
11
12
13
14
15
16
17
18
19
20
21
22
23
24
25
 |  |  |  | Totaal Excl. BTW: | 7.20

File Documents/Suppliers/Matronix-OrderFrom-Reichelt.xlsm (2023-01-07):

Bestelweb
Bestelformulier voor LED / LED Orderform
Dit formulier kan worden gebruikt voor het aanvragen (per mail) voor het plaatsen van een order in Bestelweb.
Alle opdrachten voor levering van goederen en diensten die resulteren in een factuur aan SAXION dienen in Bestelweb te worden geregistreerd. This orderform is used for requesting goods via mail.
Aanvraag
Naam/Name: |  | Matronix
Datum/Date: |  | 2022-12-03
Budgethouder: |  | Ali Yuksel
Kostenplaats: |  | 1150375
Kostensoort: |  | Parts Reichelt
Prijzen zijn exclusieve BTW / Prizes are excl. VAT
Leverancier/ Vendor: |  | Saxion
Artikelen/Articles/diensten/Services:
Nr. | Artikelnr. | Omschrijving / Description | Aantal/Quantity | Prijs/stuk (€) Price/unit (€) | Totaal (€)
1 | Reichelt | analog/digital converter ADS1115 (https://www.reichelt.nl/nl/en/raspberry-pi-analog-digital-converter-rpi-adc-p226847.html?trstct=pos_0&nbc=1) | 2.00 | 8.40 | 16.80
2 | Reichelt | Raspberry pi Stackable header 2x20 (https://www.reichelt.com/nl/de/raspberry-pi-stacking-header-40-polig-rm-2-54-rpi-header-40-p223626.html?r=1) | 1.00 | 1.35 | 1.35
3
4
5
6
7
8
9
10
11
12
13
14
15
16
17
18
19
20
21
22
23
24
25
26
 |  |  |  | Totaal Excl. BTW: | 18.15

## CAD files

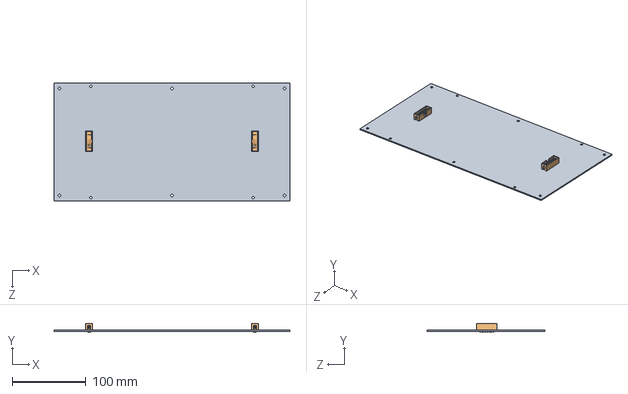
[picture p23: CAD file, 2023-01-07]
CAD/PCB assembly/PCB asembly.SLDASM
320.0 x 12.3 x 160.0 mm
Matronix main PCB outline
Box Header 8x2 16 pin x 2

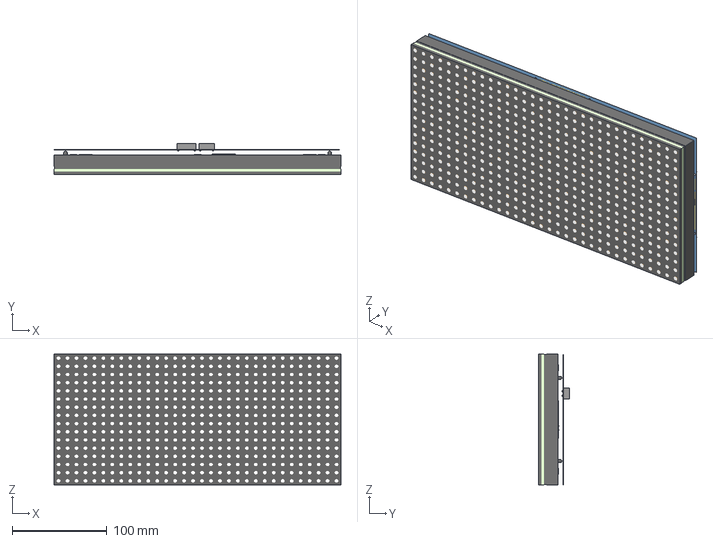
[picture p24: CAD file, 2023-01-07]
3D models/SlaveAssembly.pdf.3mf
303.4 x 32.6 x 138.4 mm

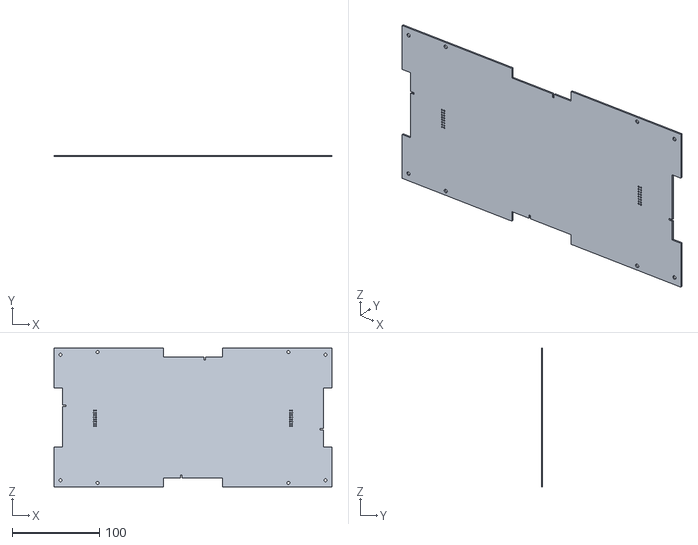
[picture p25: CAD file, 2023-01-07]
CAD/PCB assembly w Edge connectors/PCB assembly w Edge Connectors V2.STL
319.0 x 1.57 x 159.0

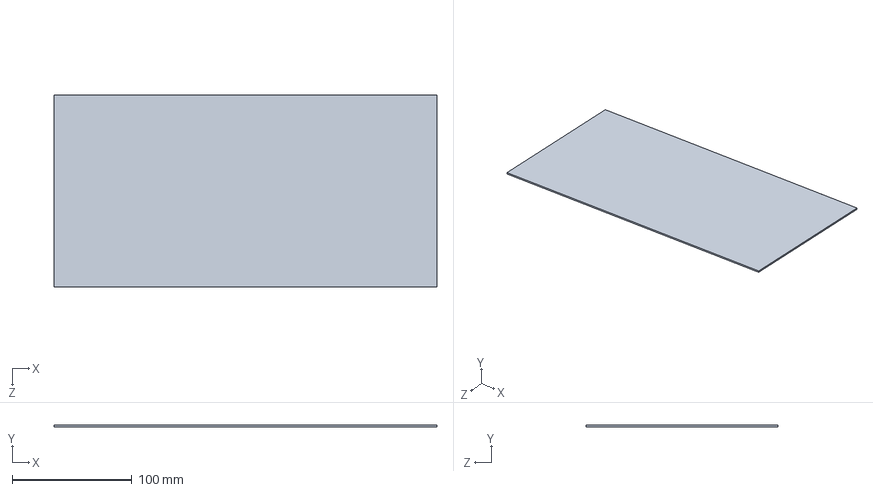
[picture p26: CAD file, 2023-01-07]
CAD/PCB assembly w Edge connectors/Matronix main PCB outline.SLDPRT
320.0 x 1.57 x 160.0 mm

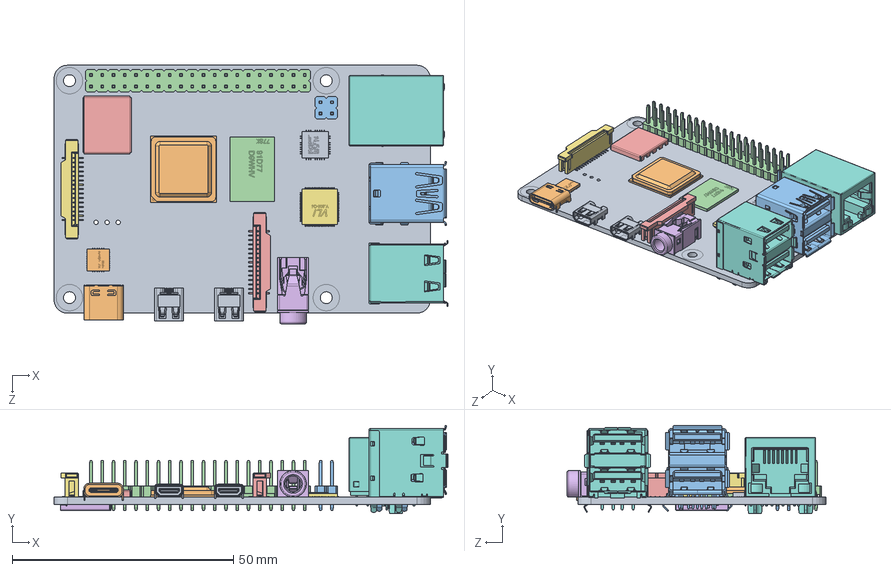
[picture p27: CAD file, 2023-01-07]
CAD/LED Matrix Display Redesign/raspberry-pi-4-model-b-1.snapshot.3/Raspberry Pi 4 Model B.SLDASM
89.0 x 19.9 x 58.4 mm
PCB, RPi4ModelB
Broadcom BCM2711B0 CPU, RPi4ModelB
2.54 mm DUPONT MALE PIN HEADER, POE, 2X2, RPi4ModelB
2.54 mm DUPONT MALE PIN HEADER, IO, 2X20, RPi4ModelB
Camera Connector, RPi4ModelB
Microphone Plug, RPi4ModelB
Display Connector, RPi4ModelB
Gigabit Ethernet Port, RPi4ModelB
Female Micro HDMI Connector, RPi4ModelB x 2
Female USB Type C Connector, RPi4ModelB
2X USB3.0 PORTS, RPi4ModelB
91D77 D9WHV 778K, 4 GB LPDDR4 SDRAM, RPi4ModelB
Cypress CYW43455 Wireless Module Cover, RPi4ModelB
SD Card Slot, RPi4ModelB
VIA VL805 PCIe USB 3.0 controller, RPi4ModelB
2X USB2.0 PORTS, RPi4ModelB
Broadcom BCM54213PE Gigabit Ethernet Transceiver, RPi4ModelB
MxL7704 Universal PMIC, RPi4ModelB

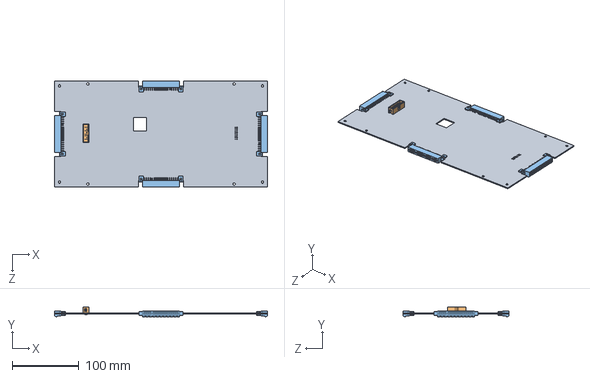
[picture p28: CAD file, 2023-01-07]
CAD/PCB assembly w Edge connectors/PCB asembly w Edge Connectors.SLDASM
319.0 x 14.9 x 159.0 mm
Matronix main PCB outline
G630H9812248EU--3DModel-STEP-56544.step x 4

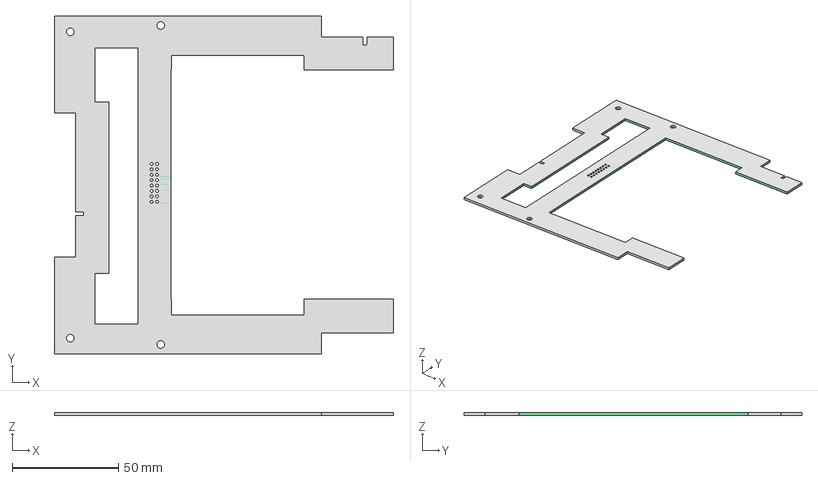
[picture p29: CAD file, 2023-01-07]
CAD/PCB assembly w Edge connectors/PCB assembly w Edge Connectors V2 Hollowed.3mf
159.5 x 159.0 x 1.52 mm

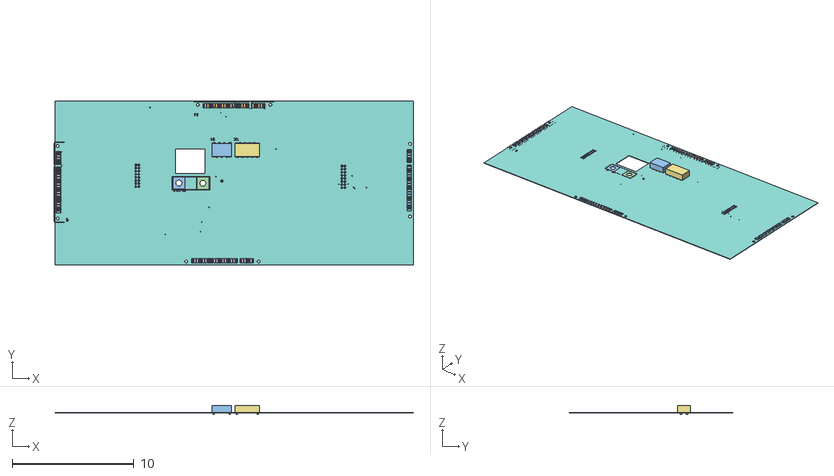
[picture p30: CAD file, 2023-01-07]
3D models/Slave.pdf.obj
29.5 x 13.5 x 0.752
Top
Bottom
5V
GND
B_BUFF
B_O
CLK_O
G1_O
G2_O
AIN2
AIN3
C_BUFF
LAT_O
A_BUFF
B2_O
E_BUFF
D_O
A_O
OE_O
R2_O
C_O
R1_O
B1_O
D_BUFF
P7
P2
P1
P6
P5
P3
ComponentBody
ComponentBody.1
ComponentBody.2
ComponentBody.3
ComponentBody.4
ComponentBody.5
Track
Solder_Top
Core
Solder_Bottom

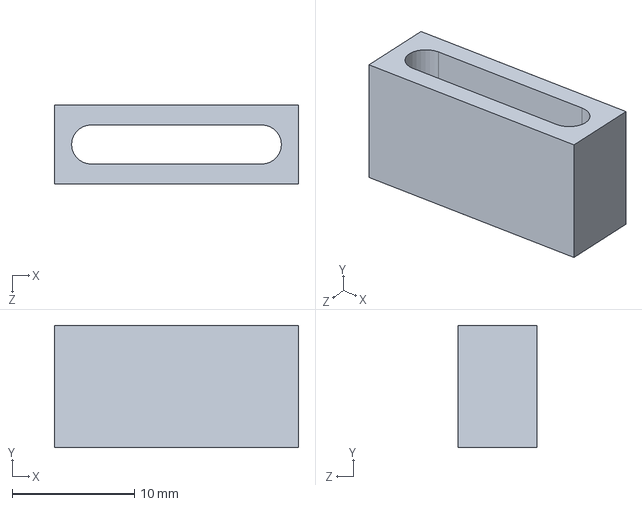
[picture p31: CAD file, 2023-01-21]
CAD/Display securing mounts.SLDPRT
20.0 x 10.0 x 6.50 mm

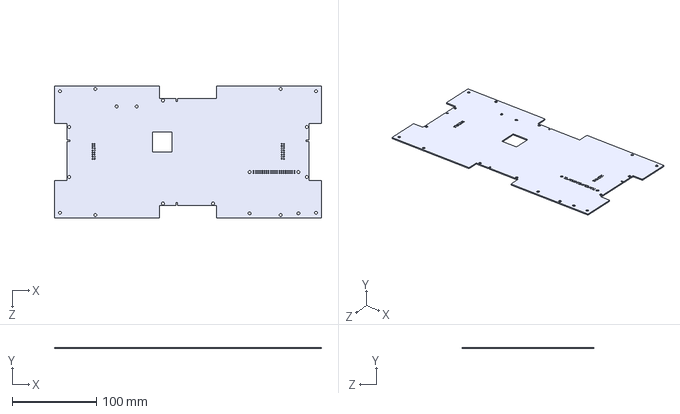
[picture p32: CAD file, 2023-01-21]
CAD/LED Matrix Display Redesign/Display_module_plate_PCB.STEP
317.5 x 1.57 x 157.5 mm

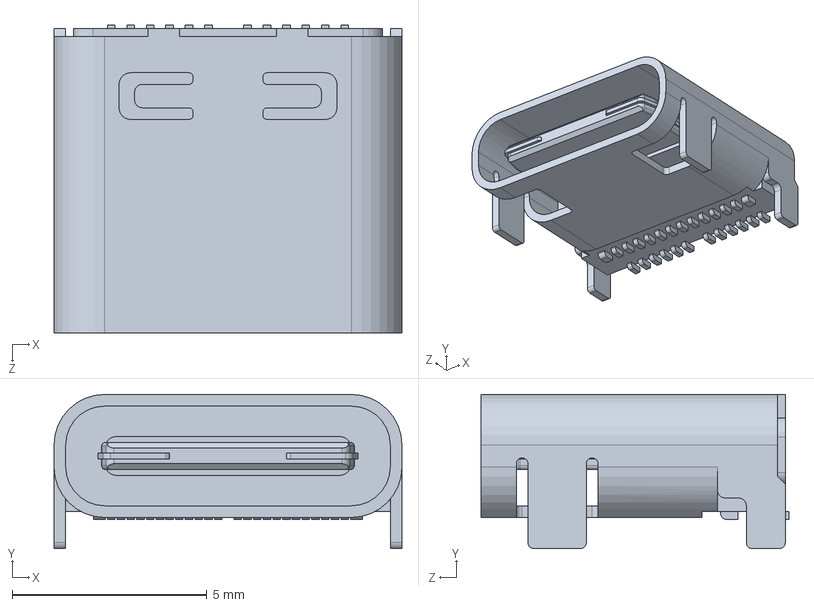
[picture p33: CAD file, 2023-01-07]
CAD/LED Matrix Display Redesign/raspberry-pi-4-model-b-1.snapshot.3/Female USB Type C Connector, RPi4ModelB.SLDPRT
8.94 x 3.96 x 7.90 mm

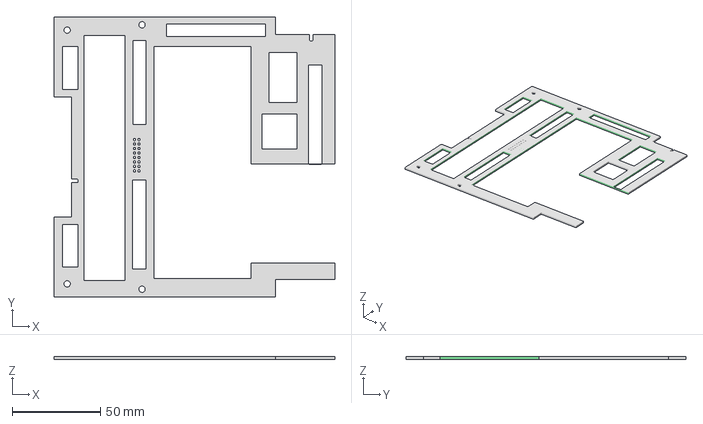
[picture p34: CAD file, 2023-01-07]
CAD/PCB assembly w Edge connectors/PCB asembly w Edge Connectors V3 Hollowed .3mf
159.5 x 159.0 x 1.52 mm

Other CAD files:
CAD/PCB assembly with all edge connectors V2/Matronix main PCB outline.SLDPRT
CAD/PCB outline with 3 edge connectors and Raspberry pi outline/Matronix main PCB outline.SLDPRT
CAD/PCB assembly/Matronix main PCB outline.SLDPRT
3D models/LED DISPLAY 32x16 Adafruit.3mf
3D models/LED DISPLAY 32x16 Adafruit.SLDPRT
3D models/raspberry-pi-4-model-b-1.snapshot.3/2.54 mm DUPONT MALE PIN HEADER, IO, 2X20, RPi4ModelB.SLDPRT
3D models/raspberry-pi-4-model-b-1.snapshot.3/2.54 mm DUPONT MALE PIN HEADER, IO, 2X40, RPi4ModelB.SLDPRT
3D models/raspberry-pi-4-model-b-1.snapshot.3/2.54 mm DUPONT MALE PIN HEADER, POE, 2X2, RPi4ModelB.SLDPRT
3D models/raspberry-pi-4-model-b-1.snapshot.3/2X USB2.0 PORTS, RPi4ModelB.SLDPRT
3D models/raspberry-pi-4-model-b-1.snapshot.3/2X USB3.0 PORTS, RPi4ModelB.SLDPRT
3D models/raspberry-pi-4-model-b-1.snapshot.3/Broadcom BCM2711B0 CPU, RPi4ModelB.SLDPRT
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

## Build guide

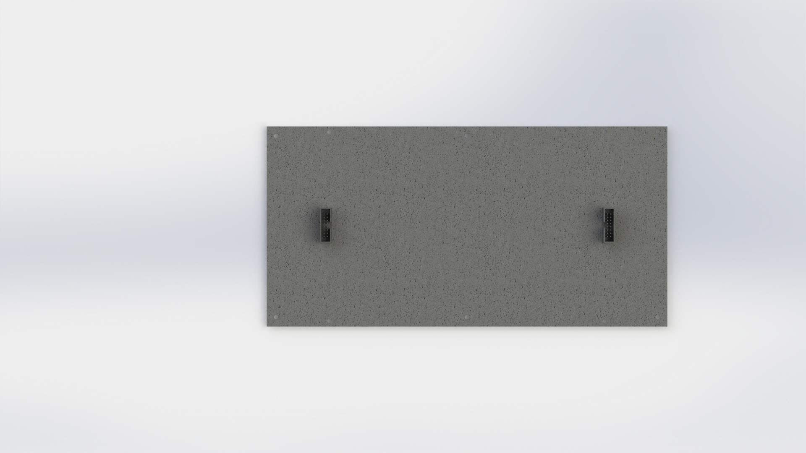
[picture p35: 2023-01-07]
CAD/PCB assembly/render.jpg

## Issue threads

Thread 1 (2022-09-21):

bad artifacts due to ESP32 Sending 3.3v logic levels

karolis1115, 2022-09-21:
ESP32 Sends 3.3v logic levels while the matrix display requires 5v logic levels causing bad artifacts, Initially insufficient current was suspected however most likely cause are the logic levels being sent from the ESP32 module

karolis1115, 2022-10-26:
Switched to Raspberry pi Issue no longer present, Closing Issue.

Closed 2022-10-26.

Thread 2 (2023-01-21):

PCB routing Errors

karolis1115, 2023-01-21:
- The main PCB has routing errors that send reversed voltage through the PCI-E connectors to the additional displays (either main PCB or Addon display PCB Fixing either one will do)

- 5v tracks to the Raspberry pi need to be thicker as currently there is a quite big voltage drop between source and the Pi
- Link board connecting additional displays is too short thus not reaching the pins between the 2 displays

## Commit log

2022-10-26 - Removed ESP32 Example & library code - Choice of controller changed to Raspberry pi 4B - Updated Docs. & Pics. - Updated Altium Files
    [Display.PcbDoc, Display.SchDoc, Matronix-OrderFrom-Full.xlsm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]
2022-11-27 Imported .dxf Drawing of Display Placed allignment-critical components into place
    [Display.PcbDoc, Display.SchDoc, Matronix.PrjPcb]
2022-11-28 FInalised (maybe) board outline Added cutout for Power connector Fixed connector orientation Fixed P6 and P7 Snap to drawing problem other minor fixes
    [Display.PcbDoc]
2022-11-29 Placed Raspberry pi Sketch and placed connector in place verified all connectors are parraller to each other and in correct places Locked components (connectors) that were in correct places
    [Board Edge Connectors.SchDoc, Display.PcbDoc]
2022-11-29 Removed Unecessary reistors from Resistor from baterry/display detection circuitry
    [Display&Baterry detection.SchDoc]
2022-11-29 Moved all connectors into 1 schematic
    [Board Edge Connectors.SchDoc, DIsplay_IO.SchDoc, Power Delivery & Comunication Connector.SchDoc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]
2022-11-29 Moved Raspberry pi down and imported outline/positionin dxf with raspberry pi outline included
    [ADC.SchDoc, Board Edge Connectors.SchDoc, Connectors.SchDoc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]
2022-11-30 Finalised critical PCB layout components (maybe again haha)
    [Connectors.SchDoc, Display.PcbDoc]
2022-12-06 Finalised Main PCB,
    Changes since last commit:
    Redid board outline and component positioning sketch (board is now flush with bottom of LED display)
    Routed, Poured polygons/ Ground plane and added stitching
    [3v3--5V Logic Level Conversion.SchDoc, Connectors.SchDoc, Display&Baterry detection.SchDoc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]
2023-01-07 Initial and Finalised commit of External PCB
    [Display.GBL, Display.GBO, Display.GBP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]
2023-01-07 Added PCB Files for all PCBs and added CAD and 3D model files used in the making of the PCBs
    [1747785-1.SLDPRT, 2.54 mm DUPONT MALE PIN HEADER, IO, 2X20, RPi4ModelB.SLDPRT, 2.54 mm DUPONT MALE PIN HEADER, IO, 2X40, RPi4ModelB.SLDPRT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]
2023-01-07 Update README.md
    Added Link to ADC Library
2023-01-21 First commit after presentation
    And possibly the last, Added some more files and cleaned up some stuff
    [AMPHENOL_G630H9812248EU.PcbLib, PCIE-Connector-PCB-side.PcbLib, PCIE-Connector-PCB-side.SchLib]
2023-01-21 - Added some files and cleaned up some other places - Added some files to the CAD folder - Added a script that allows for easier use of the display
    [1747785-1.SLDPRT, 2.54 mm DUPONT MALE PIN HEADER, IO, 2X20, RPi4ModelB.SLDPRT, 2.54 mm DUPONT MALE PIN HEADER, IO, 2X40, RPi4ModelB.SLDPRT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]
2023-01-23 Added Holes
    **NOTE** The conector placement for Main PCB is different than external PCB
    [Display.PcbDoc]
